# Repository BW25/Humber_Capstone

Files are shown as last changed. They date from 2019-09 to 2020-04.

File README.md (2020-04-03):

# Humber_Capstone
2019-2020 Computer Engineering Capstone Project at Humber College

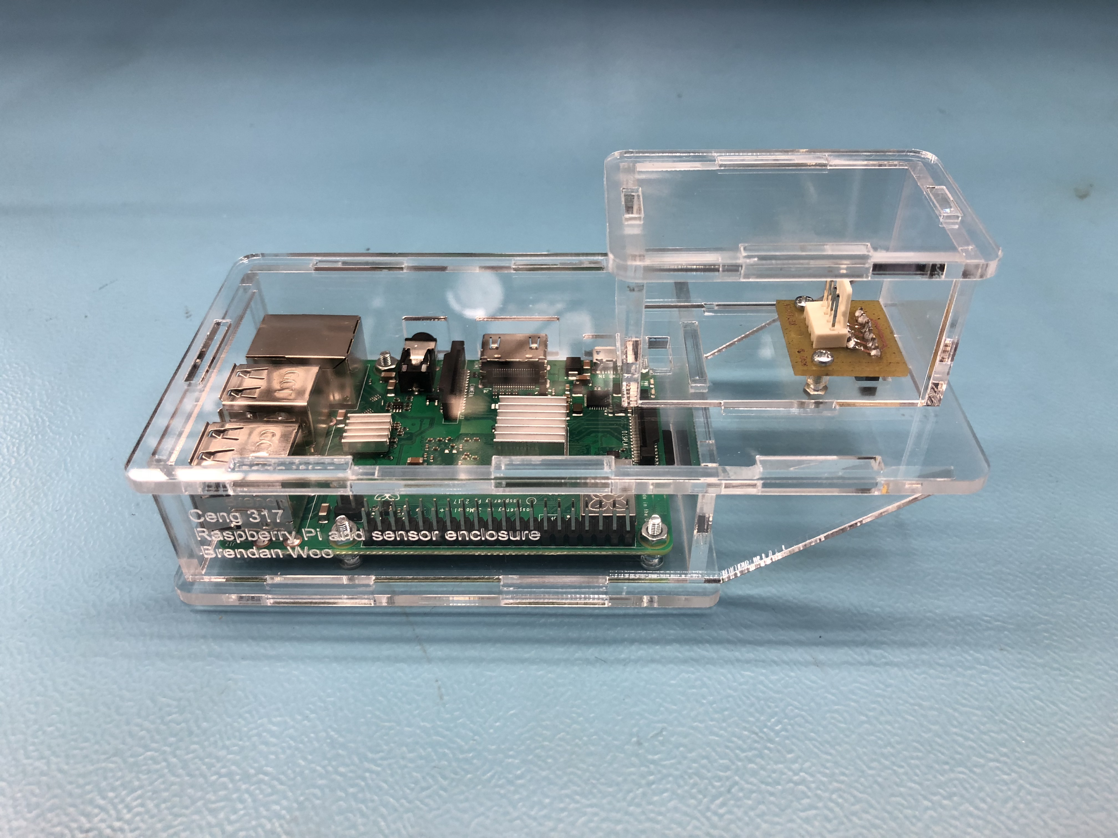
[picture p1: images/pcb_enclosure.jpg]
The final product


This guide will help you build a time-of-flight sensor, interface board, and laser-cut case for a Raspberry Pi development platform. The TOF sensor used is the VL53L0X sensor. This project was designed to serve as a piece of the hardware for a Resistor Value Recognizer device, but it can be used for other projects as well.

## Table of Contents
[Introduction](https://github.com/BW25/Resistor-value-recognizer#Introduction)

[Budget](https://github.com/BW25/Resistor-value-recognizer#Budget)

[Time committment](https://github.com/BW25/Resistor-value-recognizer#Time-committment)

[Software setup and Unit testing 1: Breadboard](https://github.com/BW25/Resistor-value-recognizer#Software-setup-and-Unit-testing-1-Breadboard)

[PCB / Soldering: Breadboard](https://github.com/BW25/Resistor-value-recognizer#PCB-/-Soldering)

[Unit testing 2: PCB](https://github.com/BW25/Resistor-value-recognizer#Unit-testing-2-PCB)

[Mechanical assembly](https://github.com/BW25/Resistor-value-recognizer#Mechanical-assembly)

[Power up and Unit testing 3: Production testing](https://github.com/BW25/Resistor-value-recognizer#Power-up-and-Unit-testing-3-Production-testing)

## Introduction

The Raspberry Pi development platform connects to the VL53L0X through an I2C bus. To make the connecttion and mounting of the sensor easier and more streamlined, an interface PCB was designed in Fritzing. The Raspberry Pi, sensor, and PCB are then enclosed in a laser-cut case for protection.

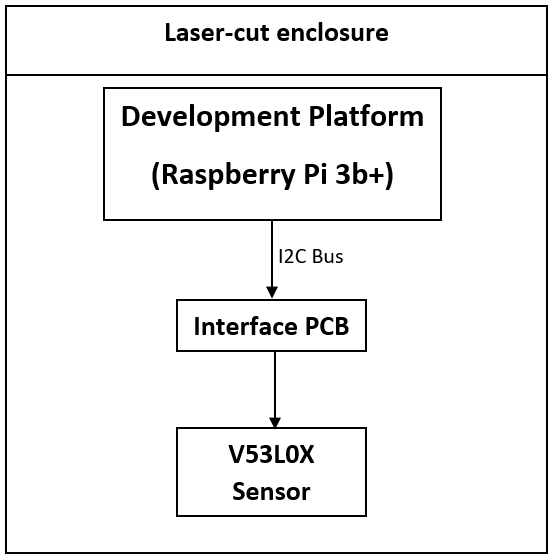
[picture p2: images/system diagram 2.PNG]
System Diagram 2

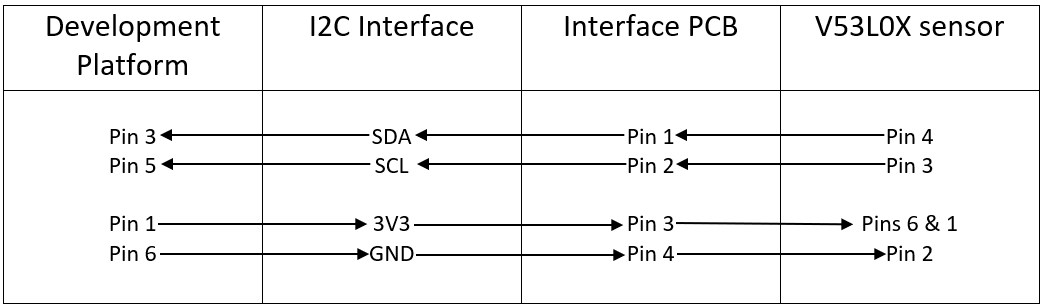
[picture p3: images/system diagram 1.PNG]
System Diagram 1


## Budget
[Full budget file](https://github.com/BW25/Resistor-value-recognizer/blob/master/documentation/Hardware%20(Ceng%20317)/Ceng317%20Budget%20BWoo%202019.xlsx)

The expected budget for the project is $144.52. However, the primary cost is a Raspberry Pi kit. If you already have one, then the cost will be $59.15. 

Here is a breakdown of all parts needed:

| Component | Number | Cost  |  Source  | Link |
|:---:|:---:|:---:|:---:|:---:|
| 3mm cast acrylic sheet | 1 |  $14.95 |  Amazon  | https://amzn.to/2Ry0JLj |
| m2.5 screws | 4 |  $0.60  |  Digikey | https://bit.ly/2t4eDuB |
| m2.5 nuts | 4 |  $0.92  |  Digikey | http://bit.ly/35lUwpC |
| m2 screws | 2 |  $0.42  |  Digikey | http://bit.ly/2PvBeYw |
| m2 nuts | 2 |  $0.34  |  Digikey | http://bit.ly/355GWqq |
| 4 pin header and 6 pin header | 1 |  $19.98 |  Amazon  | https://amzn.to/2PyRhVc |
| VL53L0X sensor | 1 |  $14.95 | Adafruit | https://www.adafruit.com/product/3317 |
| 4 F-F wire connectors | 1 |  $6.99  |  Amazon  | https://amzn.to/2RHou3L |
| Raspberry Pi kit | 1 |  $85.37 |  Canakit | https://amzn.to/2RHTccP |
| Total: | | $144.52 | | |

These components come with a Raspberry Pi Kit:

| Component | Number |
| --- | --- |
| Raspberry Pi | 1 |
| MicroSD card with Raspian | 1 |
| Raspberry Pi power supply | 1 |
| HDMI cable | 1 |

These components are expected to have no cost, as they are common enough that they are likely already possessed. The electronics are necessary to interface to the Raspberry Pi.

| Component | Number |
| --- | --- |
| Glue | 1 |
| Monitor with HDMI port | 1 |
| USB mouse | 1 |
| USB keyboard | 1 |

As shown below, the other main costs are the VL53L0X sensor and a sheet of 3mm cast acrylic for the enclosure. 

I have included resources to places where some of the resources can be purchased in the budget. Some components, such as the cast acrylic may have different availabilities depending on your location. Other components such as screws can be purchased at a local hardware store. 

I created my PCB in the Humber Prototype Lab, but you can order one from any PCB manufacturer, such as [Express PCB](https://www.expresspcb.com/how-to-order-pcbs/).
The PCB design can be edited in Fritzing, and can be found here: [PCB file](https://github.com/BW25/Resistor-value-recognizer/blob/master/electronics/TOFsensorDesign.fzz).

The AutoCAD files for the enclosure can be found here: [Hardware enclosure file](https://github.com/BW25/Resistor-value-recognizer/blob/master/mechanical/hardwareEnclosure.dwg)

## Time committment
As all design files are provided here, there is not a large expected time requirement for this project. As some components must be acquired from local retailers, additional time has been allotted to this part of the project. 
The total expected time is 3.5 hours. However, keep in mind it may take a few weeks for your parts and PCB to arrive after they have been ordered. 

| Task | Time |
| --- | --- |
| Parts order | 60 minutes |
| Breadboarding | 30 minutes |
| Soldering | 30 minutes |
| Laser cutting | 30 minutes |
| Mechanical assembly | 30 minutes |
| Power up | 15 minutes |
| Additional testing | 15 weeks |

## Software setup and Unit testing 1: Breadboard
It is recommended to test your sensor once it arrives to ensure it is functional.
This step also involves setting up the software. 

If your Raspberry Pi has not yet been set up with Raspian, you can find a step-by-step guide here.
[Raspberry Pi Tutorial](https://projects.raspberrypi.org/en/projects/raspberry-pi-setting-up)

Once your Raspberry Pi has been set up, you will need to enable the I2C bus. From the terminal, use the command "sudo raspi-config" to open the configuration window. 
Select "Interfacing Options". 
Highlight the “I2C” option and select it by pressing Enter. 
Select "Yes"
Close the configuration window

Now download the Raspberry Pi Python API.
It can be downloaded as a zip from this repository [here](https://github.com/BW25/Resistor-value-recognizer/blob/master/software/VL53L0X_rasp_python-master.zip).
Alternatively, you can download it from the [original source](https://github.com/johnbryanmoore/VL53L0X_rasp_python).

Set up your breadboard according to the wiring diagram provided. Now run the python code you downloaded. 
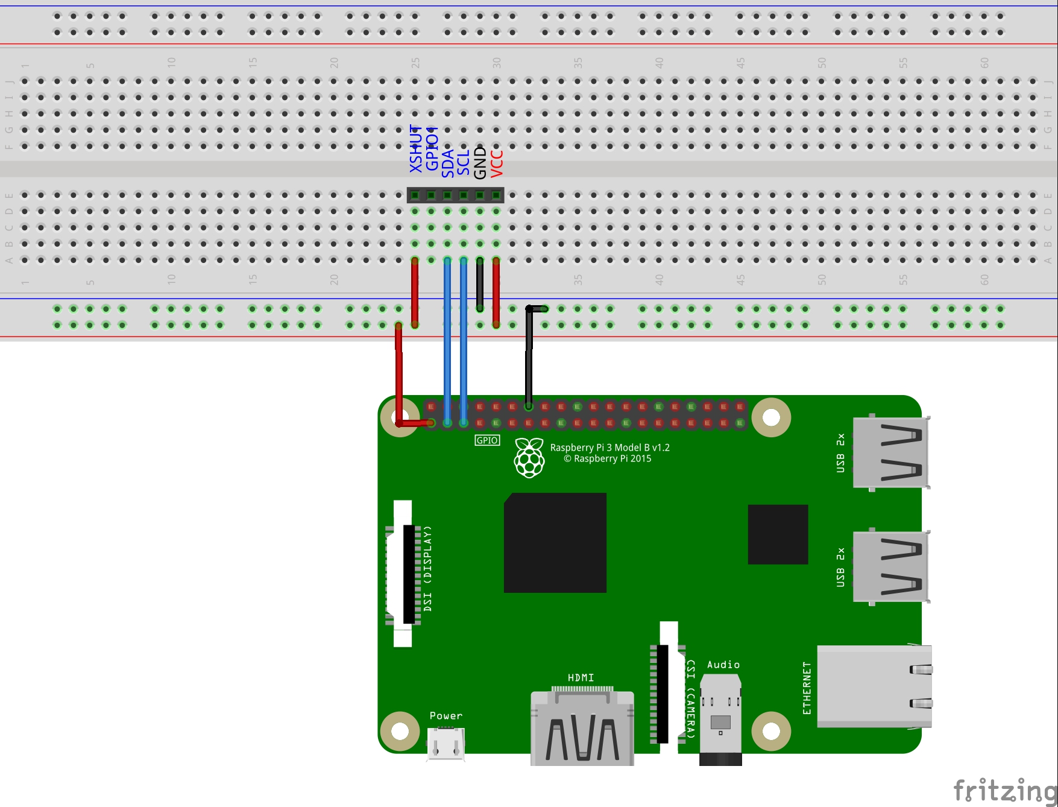
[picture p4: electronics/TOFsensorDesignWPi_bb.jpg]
Wiring diagram


Navigate to the code you downloaded and open the "python" folder. Run the python script "VL53L0X_example.py" in the command line.
If you are successful, you should see the code giving output similar to the image below. The value displayed should display the distance from the sensor to an object above it. 
Test it by moving your hand above the sensor while the code is running.

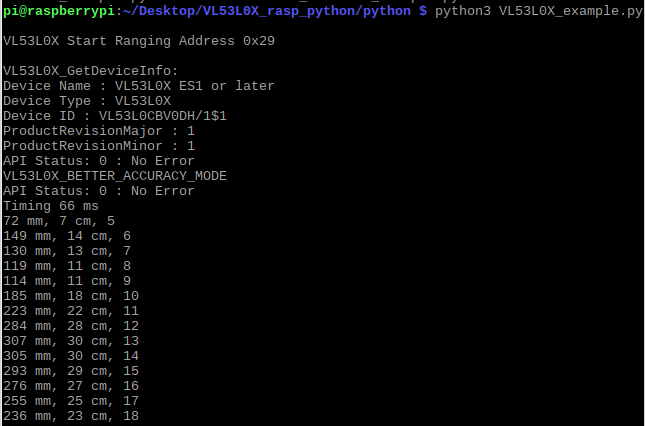
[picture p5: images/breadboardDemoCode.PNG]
Sample output


## PCB / Soldering

Once your PCB has arrived, it must be soldered. 
If you are unfamiliar with soldering, you can find a beginning tutorial here. [Soldering tutorials](https://www.youtube.com/watch?v=vIT4ra6Mo0s).

If you did not get a board with plated through holes, you will need to solder the center holes to ensure a connection between both sides of the boards. These holes are marked on the image below with black centers. Simply insert a short length of wire into the hole and solder on both ends.

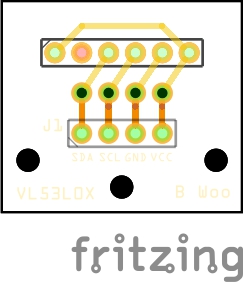
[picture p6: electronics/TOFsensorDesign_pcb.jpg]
PCB


The top side of the board is the side with the text. Do not solder the sensor directly onto the board. Instead, use a 6-pin header so the sensor can be inserted and removed without permanently attaching it to the board. Solder the 6-pin header to the bottom side of the board, and the 4 pin header to the top. The 4 pin header is where you will attach the wires between the board and the Raspberry Pi.

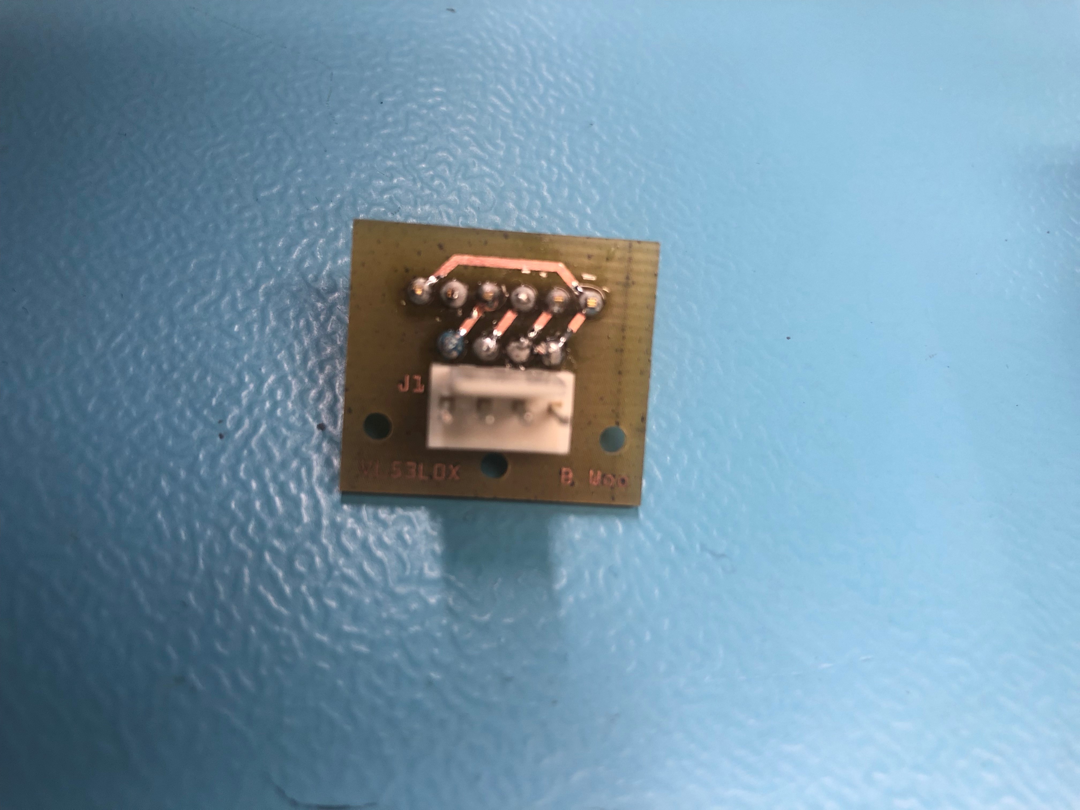
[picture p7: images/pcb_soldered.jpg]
Soldered PCB


## Unit testing 2: PCB
One your PCB is soldered, use a multimeter to ensure all of the pins are connected correctly. Refer to the labelling on the PCB itself and the schematic to ensure all pins are appropriately connected with no shorts. 
Then connect the PCB to the Raspberry Pi. You may use the same wiring on the Pi as in Unit testing 1, and the pins on the PCB are labelled, so this should be simple. Then run the code from Unit testing 1 to ensure the sensor and board are connected correctly. 
If it does not work, then recheck you interface board with a multimeter as above. If you cannot find a problem with the PCB, it may be necessary to recheck your sensor or Pi setup by repeating unit testing 1.

## Mechanical assembly

If you are unfamiliar with laser cutting, you can find a guide here. [Introduction to laser cutting](https://makerdesignlab.com/tutorials-tips/laser-cutting-beginners-guide/)

Laser cutting can be done in your local makerspace. A quick Internet search should let you find the one closest to you.

This project is designed for 3mm cast acrylic; colour is irrelevant, although I used transparent acrylic. You can cut other materials, but keep in mind the slots on the design are designed for a 3mm thick material. You may need to alter the design if you want to use something else. 
The AutoCAD files can be found at this link. I recommend altering it to change the text at minimum; you want it to say your name, not mine! [Hardware enclosure](https://github.com/BW25/Resistor-value-recognizer/blob/master/mechanical/hardwareEnclosure.dwg)

If you are unfamiliar with AutoCAD, you can find tutorials here. [AutoCAD tutorials](https://thesourcecad.com/autocad-tutorials/).

After editing the AutoCAD files, go to the "Output" tab and select "Plot". Change the plot scale to 1:1 in mm. Use the Preview button and the Plot offset to ensure your design is centered on the paper. Then select "Ok" to output your design to a PDF. 

If you do not wish to alter the enclosure, you may use this PDF output instead. [Hardware PDF](https://github.com/BW25/Resistor-value-recognizer/blob/master/mechanical/hardwareEnclosure-Model.pdf)

Bring your output PDF and and AutoCad files to the makerspace where you will laser cut your case. As the makerspace where you cut the acrylic could have a different model of laser cutter, please speak to the staff there for instructions on its use.

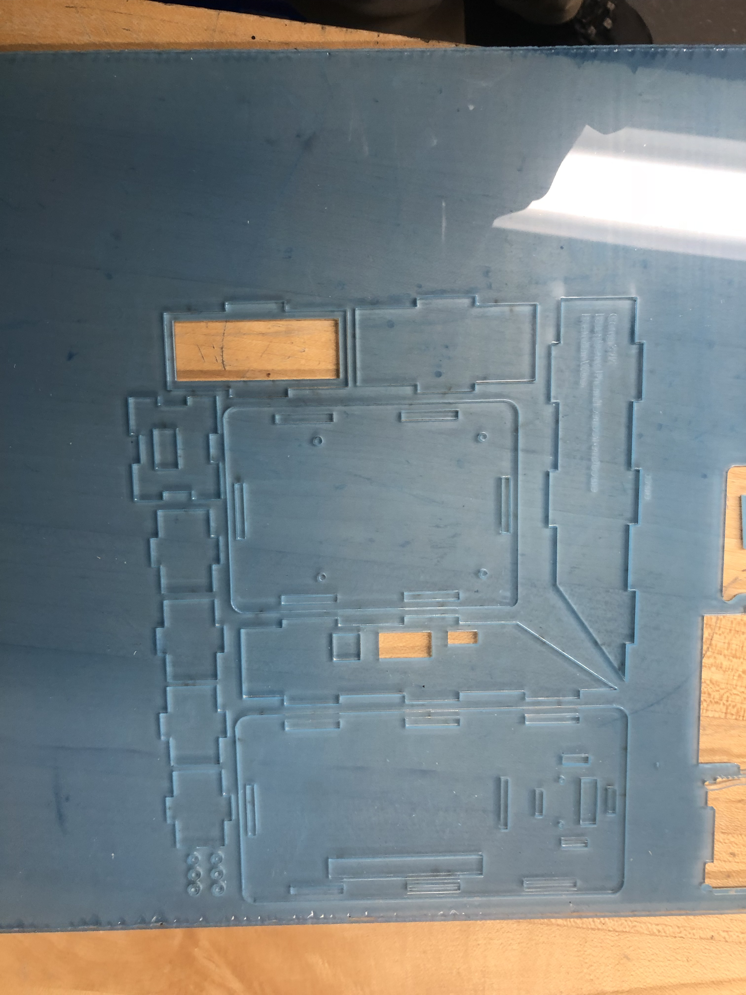
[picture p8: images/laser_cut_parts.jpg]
Laser cut pieces


The design is assembled shown in the image. Be sure that the side pieces with the holes are lined up with the ports on you Raspberry Pi. The small donut shaped pieces are standoffs for mounting your Raspberry Pi and PCB. Use the four larger standoffs and 4 m2.5 screws and nuts for the Raspberry Pi. The 2 smaller standoffs and 2 m2 screws and nuts are for your PCB. You may use acrylic glue to hold your case together. However, be sure not to glue the tops onto the case; friction will hold it in place, and gluing it shut means you can't remove your Raspberry Pi and PCB!

The final product

## Power up and Unit testing 3: Production testing

The final test is to interface our sensor to the Raspberry Pi in the case. Once the case is assembled, you will notice a small hole in the lid of the case. You can run the wires through here to connect the sensor and Raspberry Pi. Then connect the wiring and run the code as explained in Unit testing 1 and 2.

If you are assembling this project in larger numbers or are pressed for time, the multiple stages of unit testing may be undesirable or redundant. Therefore, this final check can be used for production testing.

If any clarification or assistance is required, please post in the Issues section.

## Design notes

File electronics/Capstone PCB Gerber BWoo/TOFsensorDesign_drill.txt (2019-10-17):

; NON-PLATED HOLES START AT T1
; THROUGH (PLATED) HOLES START AT T100
M48
INCH
T1C0.086614
T100C0.038000
T101C0.039370
%
T1
X008014Y001971
X004503Y000974
X001014Y001971
T100
X005014Y002971
X004014Y002971
X005014Y005971
X007014Y005971
X003014Y002971
X004014Y005971
X006014Y002971
X002014Y005971
X006014Y005971
X003014Y005971
T101
X004014Y004478
X005014Y004478
X006014Y004470
X003014Y004478
T00
M30

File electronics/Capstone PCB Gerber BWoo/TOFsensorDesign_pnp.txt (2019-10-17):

*Pick And Place List
*Company=
*Author=
*eMail=
*
*Project=TOFsensorDesign
*Date=14:49:19
*CreatedBy=Fritzing 0.9.3b.04.19.5c895d327c44a3114e5fcc9d8260daf0cbb52806
*
*
*Coordinates in mm, always center of component
*Origin 0/0=Lower left corner of PCB
*Rotation in degree (0-360, math. pos.)
*
*No;Value;Package;X;Y;Rotation;Side;Name
1;;;5.17913;-1.68191;0;Top;TXT1
2;;;12.751;-5.15002;0;Top;TXT1
3;;;19.1006;-1.83685;0;Top;TXT1
4;;;10.1972;-11.3746;0;Bottom;Via3
5;;;10.3267;-5.16554;0;Top;TXT1
6;;;2.57712;-5.00764;0;Bottom;Hole3
7;;;4.8855;-8.12504;0;Top;TXT1
8;;;11.4392;-2.47526;0;Bottom;Hole4
9;;;7.65722;-11.3746;0;Bottom;Via4
10;;THT;11.4672;-7.54754;-90;Bottom;J3
11;;;7.72183;-5.16865;0;Top;TXT1
12;;;12.7372;-11.3746;0;Bottom;Via2
13;;;15.1925;-5.1709;0;Top;TXT1
14;;;15.2772;-11.3563;0;Bottom;Via1
15;;;20.3571;-5.00764;0;Bottom;Hole1
16;;THT;11.4672;-15.1675;-90;Bottom;J2

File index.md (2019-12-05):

## Blog
### Resistor Value Recognizer
#### Brendan Woo, Husnal Kaur

## Repository
[https://github.com/BW25/Resistor-value-recognizer](https://github.com/BW25/Resistor-value-recognizer "Repository")

### November 28, 2019 (Week 11)

The presentation has been completed, and the project is proceeding on schedule.

As previously stated, the budget is also on track

[Presentation](https://github.com/BW25/Resistor-value-recognizer/blob/master/documentation/Hardware%20(Ceng%20317)/Project%20Presentation.pptx)

### November 21, 2019 (Week 10)
The PCB enclosure has been created, and now all hardware and software has been completed.

With no more expenses left to make, the final budget is as detailed in the budget.

The project is also on schedule, and work is beginning on the project presentation and build instructions.

PCB enclosure

### November 14, 2019 (Week 9)
The PCB has been tested with the development platform.

With the PCB confirmed to be functional, work is now beginning on the hardware enclosure, as per the project schedule.

The proposal is being adhered to, and the project is on budget.

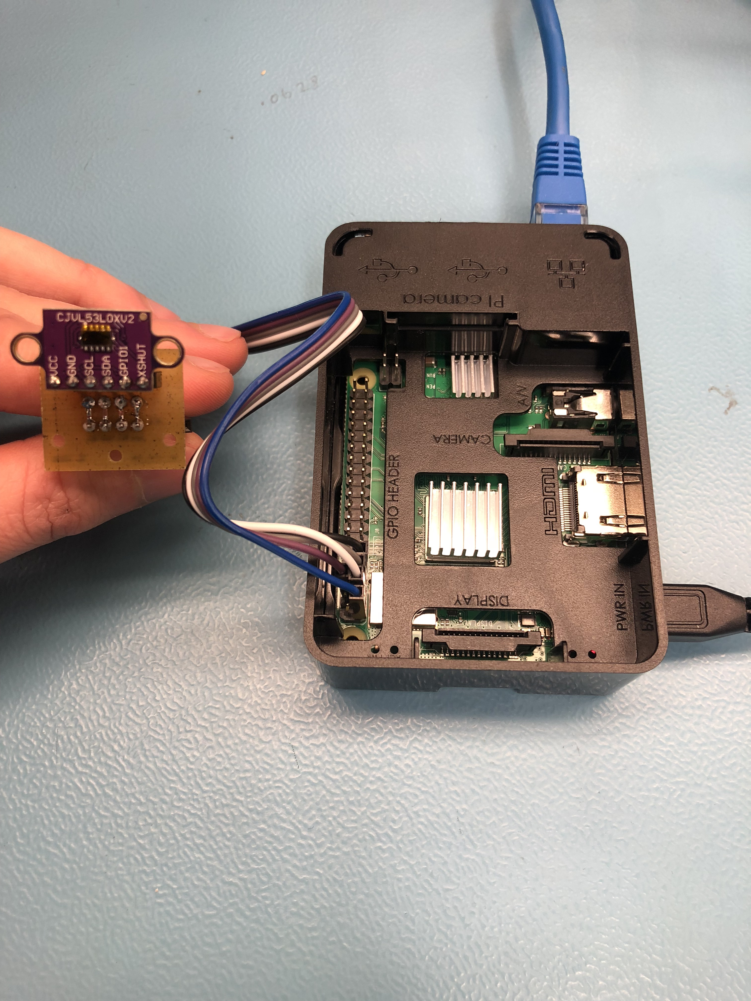
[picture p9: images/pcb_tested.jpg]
PCB tested


### November 7, 2019 (Week 9)
The PCB has been soldered and tested.

The project is on schedule and on budget.

PCB

### October 31, 2019 (Week 8)
The breadboard demo is now complete, and the sensor tested. Happy Halloween!

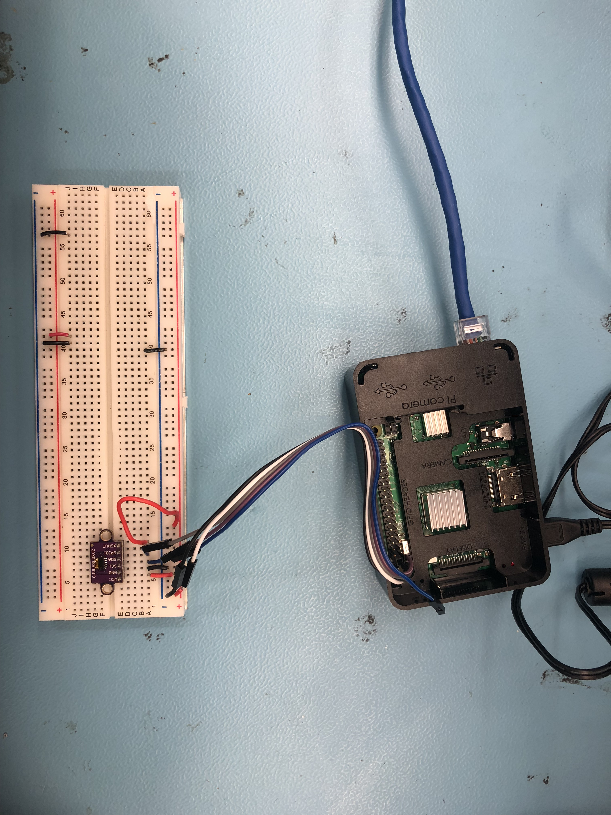
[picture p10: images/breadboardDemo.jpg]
Breadboard


Breadboard Code

### October 10, 2019 (Week 6)
The breadboard, schematic, and PCB designs are now complete.

All components needed for the breadboard have also been purchased.

The project is on track in terms of both the schedule and the budget, and the proposal is being followed.

Breadboard

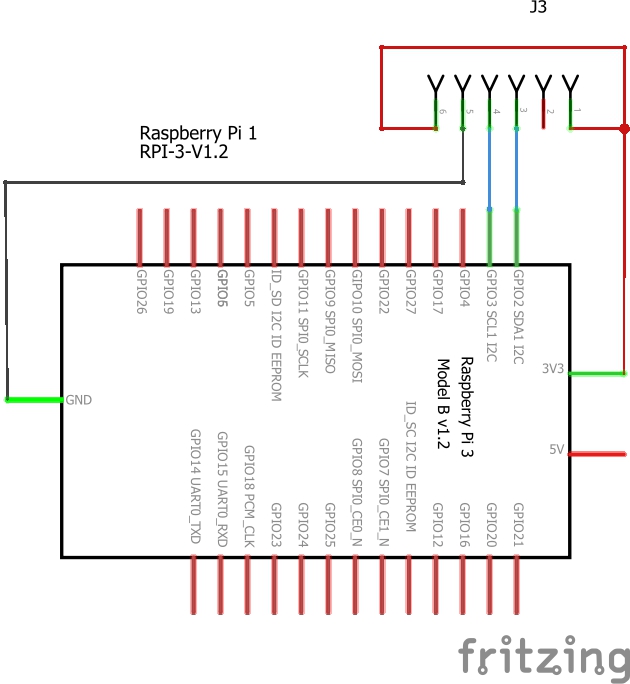
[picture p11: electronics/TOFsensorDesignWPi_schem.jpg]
Schematic


PCB

### October 03, 2019 (Week 5)
Parts have been ordered, and some have already arrived

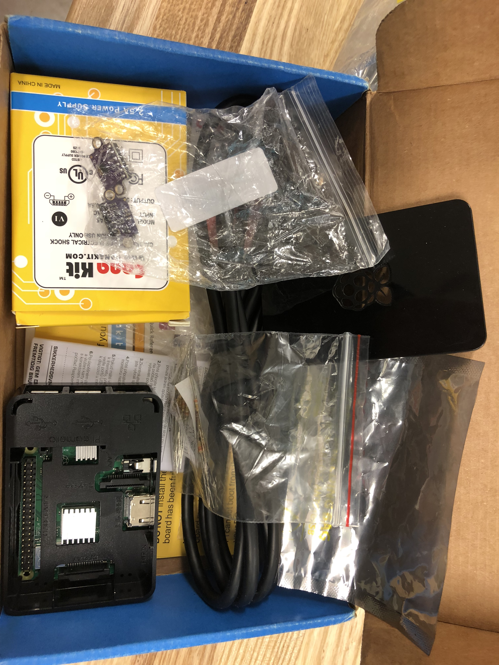
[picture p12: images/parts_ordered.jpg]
Parts Ordered Image Parts Ordered


### September 26, 2019 (Week 4)
[App layout mockup created](https://github.com/BW25/Resistor-value-recognizer/blob/master/documentation/Software%20(Ceng%20319)/Ceng%20319%20App%20mockup%20BWoo%20HKaur.pdf "App Mockup")

[App schedule created](https://github.com/BW25/Resistor-value-recognizer/blob/master/documentation/Software%20(Ceng%20319)/Ceng319%20Project%20Schedule%20Husnal%20Brendan.pdf "App schedule")

### September 19, 2019 (Week 3)
Working on colour recognition to read the resistor colour code.

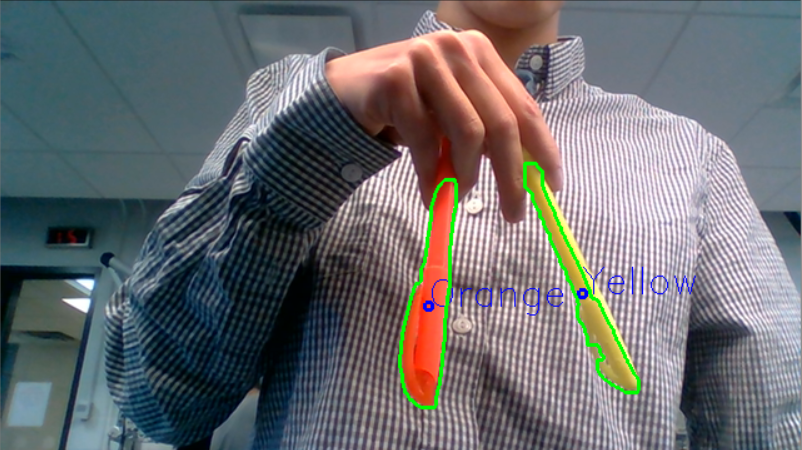
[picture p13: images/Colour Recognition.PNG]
Colour Recognition Image Colour Recognition


[Project budget written](https://github.com/BW25/Resistor-value-recognizer/blob/master/documentation/Hardware%20(Ceng%20317)/Ceng317%20Budget%20BWoo%202019.xlsx "Budget")

### September 12, 2019 (Week 2)
[Project schedule written](https://github.com/BW25/Resistor-value-recognizer/blob/master/documentation/Hardware%20(Ceng%20317)/Ceng317%20Project%20Schedule%20BWoo.png "Schedule")

### September 5, 2019 (Week 1)
This project will be a resistor value recognizer to help employees at Humber's Parts Crib as well as new students to quickly identify and organize resistors. It will include a base station that connects to an Android app.

[Project proposal written](https://github.com/BW25/Resistor-value-recognizer/blob/master/documentation/Hardware%20(Ceng%20317)/Ceng317_Proposal_ResistorValueRecognizer_Kaur-Woo.pdf "Proposal")

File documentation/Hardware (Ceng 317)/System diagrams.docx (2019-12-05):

Development Platform | I2C Interface | Interface PCB | V53L0X sensor
Pin 3 Pin 5 Pin 1 Pin 6 | SDA SCL 3V3 GND | Pin 1 Pin 2 Pin 3 Pin 4 | Pin 4 Pin 3 Pins 6 & 1 Pin 2

Laser-cut enclosure

V53L0X Sensor

I2C Bus

Interface PCB

Development Platform

(Raspberry Pi 3b+)

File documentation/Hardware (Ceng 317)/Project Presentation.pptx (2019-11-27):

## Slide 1

TOF sensor for Resistor Value Recognizer

Ceng 317
Brendan Woo

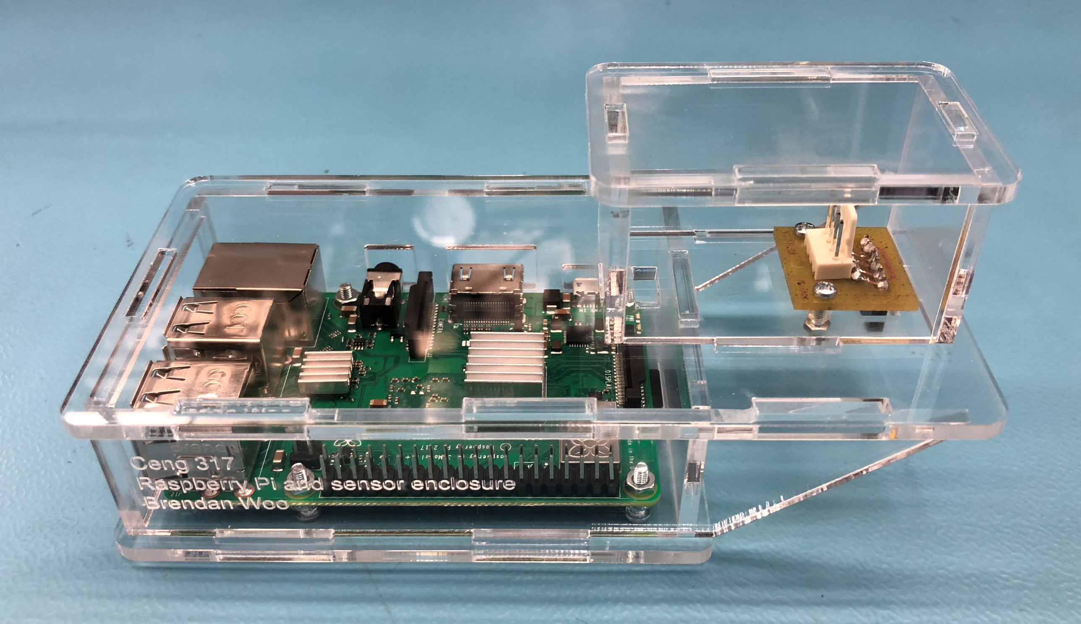
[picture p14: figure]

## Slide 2

Proposal

- The Capstone is a Resistor Value Recognizer to reduce traffic at the Parts Crib
- The camera and lighting system must be
triggered by the insertion of a resistor
- A Time of Flight infrared sensor will be used to
detect the movement for this purpose

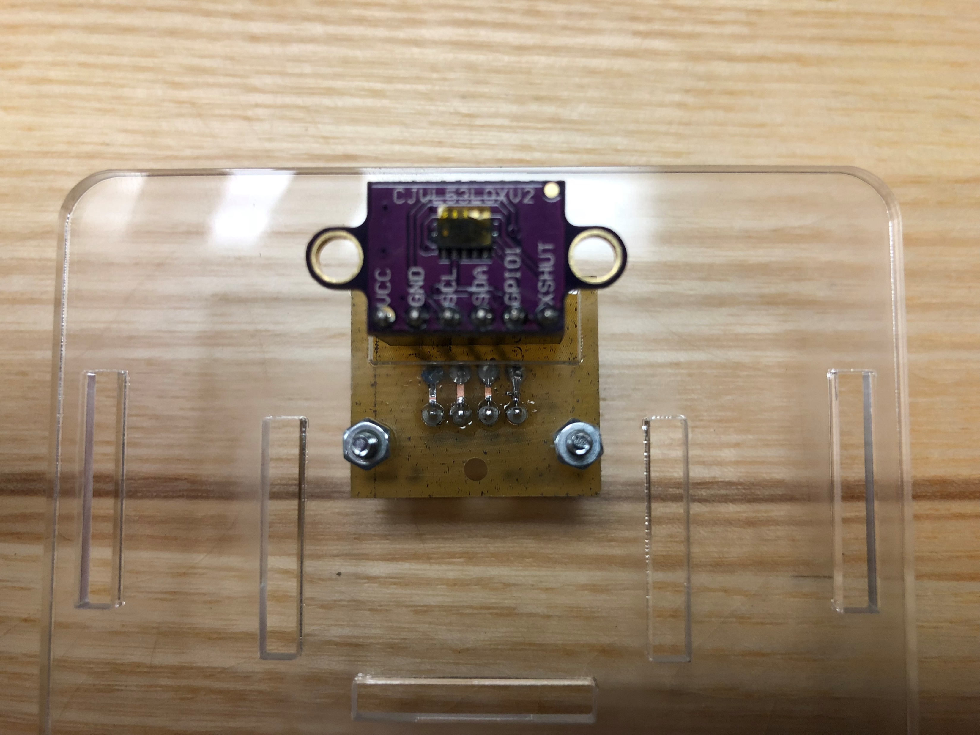
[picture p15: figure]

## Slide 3

Expenses

- Original projected budget was $124.19
- Many components were already acquired or supplied by the Prototype lab:
As a result, final expenses were $105.89
- Total expenses during the course of the project were $5.57

Purchase | Cost | Number | Total cost | Notes | Status | Source
VL53L0X TOF sensor | $14.95 | 1 | $ 14.95 | | Previously purchased | https://www.adafruit.com/product/3317
23x11 3mm transparent cast acrylic | $11.30 | 1 | $ 11.30 | For case | No cost | Supplied by prototype lab
Standoffs M-M (x4) | $2.50 | 1 | $ 2.50 | For case | No cost | Supplied by prototype lab
Standoffs M-F (x2) | $1.50 | 2 | $ 3.00 | For case | No cost | Supplied by prototype lab
Screws | $1.50 | 1 | $ 1.50 | For case | No cost | Supplied by prototype lab
Wires | $0.00 | 0 | $ - | | Previously purchased
Header pin and connectors | $ 5.57 | 1 | $ 5.57 | | | Sayal
Raspberry Pi kit | $ 85.37 | 1 | $ 85.37 | Current price is lower | Previously purchased | https://www.amazon.com/CanaKit-Raspberry-Complete-Starter-Kit/dp/B01C6Q2GSY
Expected budget | $124.19
Total | $105.89
Total project-specific | $5.57

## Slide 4

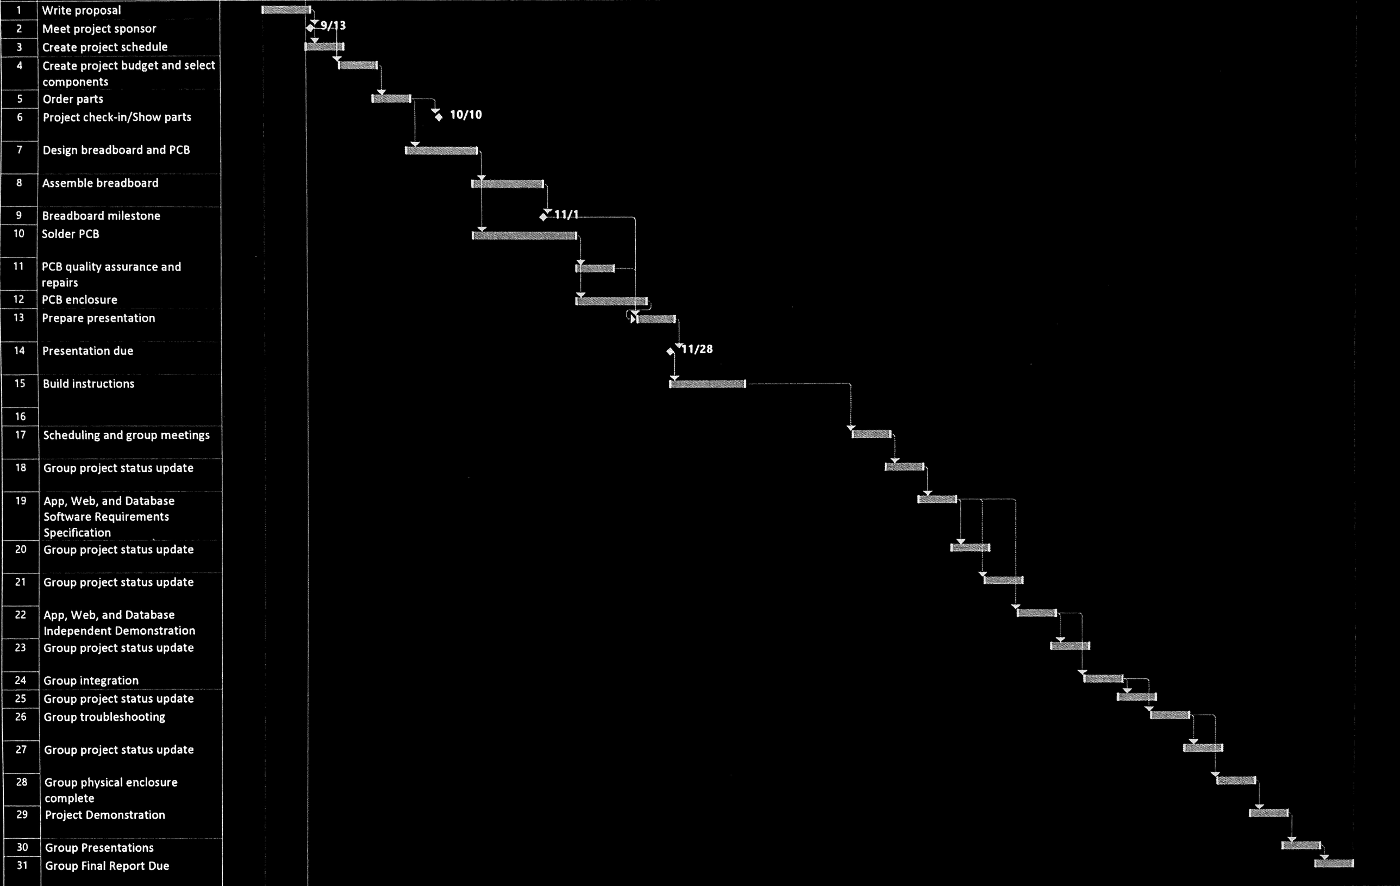
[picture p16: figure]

Schedule

- Proposal
- Schedule
- Budget
- Breadboard milestone
- PCB milestone
- Enclosure milestone
- Presentation
- Build instructions

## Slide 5

Final Product

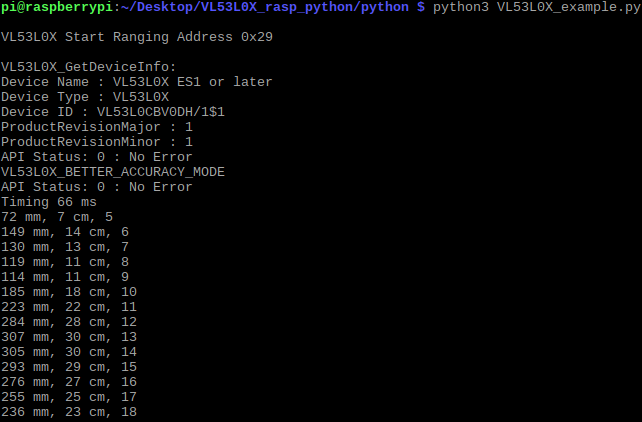
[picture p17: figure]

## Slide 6

Applied Knowledge

- Tech 150: Electronic Devices and Circuits
  - Soldering, breadboarding, circuit troubleshooting
- Ceng 252: Embedded Systems
  - Prototyping and programming on Raspberry Pi development platform
- Ceng 215: Digital and Interface Systems
  - Sensor control and interfacing

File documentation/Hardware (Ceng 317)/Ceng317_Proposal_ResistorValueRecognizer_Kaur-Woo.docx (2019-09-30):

43718

Proposal for the development of Resistor value recognizer

Prepared by Brendan Woo, Husnal Kaur
Computer Engineering Technology Students
https://github.com/BW25/Resistor-value-recognizer

Executive Summary

As a student in the Computer Engineering Technology program, I will be integrating the knowledge and skills I have learned from our program into this Internet of Things themed capstone project. This proposal requests the approval to build the hardware portion that will connect to a database as well as to a mobile device application. The internet connected hardware will include a custom PCB with the following sensors and actuators Time-of-flight sensor , luminosity sensor, camera. The database will store User account information, History of recognized resistors, Resistor color code lookup table,. The mobile device functionality will include Viewing value of resistor, Viewing history, Color code table with values and will be further detailed in the mobile application proposal. I will be collaborating with the following company/department Humber parts crib. In the winter semester I plan to form a group with the following students, who are also building similar hardware this term and working on the mobile application with me Brendan Woo, Husnal Kaur. The hardware will be completed in CENG 317 Hardware Production Techniques independently and the application will be completed in CENG 319 Software Project. These will be integrated together in the subsequent term in CENG 355 Computer Systems Project as a member of a 2 or 3 student group.

Background

The problem solved by this project is Due to the large volume of students that use the parts crib, large amounts of unsorted components often accumulate. High traffic makes it difficult to sort these components, and it is often time consuming to figure out each and every value of the resistors. Also, it can be hard to identify resistor values correctly in a fast paced environment.. A bit of background about this topic is When a component is inserted into a processing area, image processing and machine learning will be used to recognize resistor values through object and colour recognition. Once the resistor's value has been found, this can be logged in a database to track usage. This information can be accessed by an Android app so the user’s ID can be used to look up their history. A time-of-flight sensor will be used to detect when an object is inserted. As image processing techniques are dependent on lighting, a luminosity sensor will be used to trigger a lighting system to ensure ideal lighting conditions are always present. The time-of-flight sensor will then trigger both the camera and the lighting system for greater energy efficiency..

Existing products on the market include [1]. I have searched for prior art via Humber’s IEEE subscription selecting “My Subscribed Content”[2] and have found and read [3] which provides insight into similar efforts.

In the Computer Engineering Technology program we have learned about the following topics from the respective relevant courses:

- Java Docs from CENG 212 Programming Techniques In Java,
- Construction of circuits from CENG 215 Digital And Interfacing Systems,
- Rapid application development and Gantt charts from CENG 216 Intro to Software Engineering,
- Micro computing from CENG 252 Embedded Systems,
- SQL from CENG 254 Database With Java,
- Web access of databases from CENG 256 Internet Scripting; and,
- Wireless protocols such as 802.11 from TECH152 Telecom Networks.

This knowledge and skill set will enable me to build the subsystems and integrate them together as my capstone project.

Methodology

This proposal is assigned in the first week of class and is due at the beginning of class in the second week of the fall semester. My coursework will focus on the first two of the 3 phases of this project:
Phase 1 Hardware build.
Phase 2 System integration.
Phase 3 Demonstration to future employers.

Phase 1 Hardware build

The hardware build will be completed in the fall term. It will fit within the CENG Project maximum dimensions of 12 13/16" x 6" x 2 7/8" (32.5cm x 15.25cm x 7.25cm) which represents the space below the tray in the parts kit. The highest AC voltage that will be used is 16Vrms from a wall adaptor from which +/- 15V or as high as 45 VDC can be obtained. Maximum power consumption will be 20 Watts.

Phase 2 System integration

The system integration will be completed in the fall term.

Phase 3 Demonstration to future employers

This project will showcase the knowledge and skills that I have learned to potential employers.

The brief description below provides rough effort and non-labour estimates respectively for each phase. A Gantt chart will be added by week 3 to provide more project schedule details and a more complete budget will be added by week 4. It is important to start tasks as soon as possible to be able to meet deadlines.

cast acrylic for component casings, time-of-flight sensor, luminosity sensor, Raspberry Pi camera module, assorted screws, standoffs, and bolts

Concluding remarks

This proposal presents a plan for providing an IoT solution for This system will make it easier for both students and professionals to recognize resistor values in a fast and efficient manner.. This is an opportunity to integrate the knowledge and skills developed in our program to create a collaborative IoT capstone project demonstrating my ability to learn how to support projects such as the initiative described by [3]. I request approval of this project.

References

[1] Amazon. (2019, September 05). Amazon Go. Retrieved from Amazon.com: https://www.amazon.com/b?node=16008589011

[2] Institute of Electrical and Electronics Engineers. (2015, August 28). IEEE Xplore Digital Library [Online]. Available: https://ieeexplore.ieee.org/search/advsearch.jsp

[3] Cruz, J., Dimaala, M., Francisco, L., Franco, E., & Bandala, A. (2013). Object recognition and detection by shape and color pattern recognition utilizing Artificial Neural Networks. 2013 International Conference of Information and Communication Technology (ICoICT).

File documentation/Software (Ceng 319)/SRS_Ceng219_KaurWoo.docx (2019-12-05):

# Software Requirements Specification

# for

# Resistor Value Recognizer

Version 1.0 approved

Prepared by Husnal Kaur, Brendan Woo

Humber College Computer Engineering Technology

2019-10-02

Table of Contents

1. Introduction 1

1.1 Purpose 1

1.2 Product Scope 1

1.3 Intended Audience and Reading Suggestions 1

1.4 References 1

2. Overall Description 1

2.1 Product Perspective 1

2.2 Product Functions 2

2.3 User Classes and Characteristics 2

2.4 Operating Environment 2

2.5 Design and Implementation Constraints 2

2.6 User Documentation 2

2.7 Assumptions and Dependencies 2

3. External Interface Requirements 3

3.1 User Interfaces 3

3.2 Hardware Interfaces 3

3.3 Communications Interfaces 3

4. System Features 3

4.1 System Feature 1 3

4.2 System Feature 2 (and so on) 4

5. Other Nonfunctional Requirements 4

5.1 Performance Requirements 4

5.2 Safety Requirements 4

5.3 Security Requirements 4

5.4 Software Quality Attributes 4

5.5 Business Rules 5

6. Other Requirements 5

Revision History

Name | Date | Reason For Changes | Version
Woo, Kaur | 2019-10-02 | Initial report | 1.0

# 1. Introduction

## 1.1 Purpose

The project is a Resistor Value Recognizer (RVR) app. Its main functionality is to connect to a device which scans and displays the colour coded value of a resistor. Due to the large volume of students that use the parts crib, significant amounts of unsorted components often accumulate from returned components. High traffic makes it difficult to sort these components quickly, and it is often time consuming to figure out each and every value of the resistors. Moreover, it can be hard to identify resistor values correctly in a fast-paced environment. Current revision number is 1.0.

## 1.2 Product Scope

The app communicates with a database which records usage of the Resistor Value Recognizer hardware platform for each user. It also provides an interface with which to communicate with the companion device and a GUI to view resistor values. Both live scans and the history of previous scans can be viewed via the app, making for easy organizing of resistors. The goal is to provide a user-friendly means of controlling the device and accessing their data hosted on the server.

## 1.3 Intended Audience and Reading Suggestions

This document is targeted towards the following types of audience:

- Humber College Parts Crib Employees
- Students from various Schools, Colleges and Universities
- Professionals working in a fast paced environment
- Developers looking to develop applications interfacing with the server

For the best understanding of this document, the readers are suggested to become familiar with concepts like server, database, GUI(Graphical User Interface) and information communication.

## 1.4 References

These sources were used in the ideation of this project, and can be used for reference.

- Amazon. (2019, September 05). Amazon Go. Retrieved from Amazon.com: https://www.amazon.com/b?node=16008589011
- Cruz, J., Dimaala, M., Francisco, L., Franco, E., & Bandala, A. (2013). Object recognition and detection by shape and color pattern recognition utilizing Artificial Neural Networks. 2013 International Conference of Information and Communication Technology (ICoICT).

# 2. Overall Description

## 2.1 Product Perspective

This project is a Capstone Project for Humber College’s Computer Engineering Technology program. As a result, this is a standalone project consisting of both the hardware and software of a companion device, a web server, and the Android app. The app and companion device will communicate via the web server, which stores relevant user data as well as data used to control the companion device from the app.

Data flow:

Companion Device

Web server

Android App

## 2.2 Product Functions

The app provides the following core functionalities, explained further in Section 3

- Communications with the database
- History viewing
- Resistor Color Code Lookup table
- User account management

## 2.3 User Classes and Characteristics

This application and the companion device are mainly targeted towards three different types of users:

1. Humber College Parts Crib: The parts crib has, at any given time, high amount of various components which are to be sorted in different spaces. This device and app will help them quickly identify resistor values without going through the process of calculating them manually.
2. Students (Schools/Colleges/University): Students who are unfamiliar with resistor color codes and how to calculate the values of resistors can easily use the app and the device to find the value without having to look up online.
3. Professionals working in a fast paced environment: This app will bring ease of resistor identification to professionals who use multitude of resistors on a daily basis. It will be easier and faster for them to get the values and store them in the history of the application than either calculating the value every time or putting the resistor inside the physical device again.

## 2.4 Operating Environment

The software will operate as an app on an Android phone running Android 7 (Nougat), API 24. The targeted minimum API of the app is 19 (Kitkat) to ensure compatibility. It must run alongside other applications which may be making use of the same hardware resources, including the camera and Wi-Fi.

## 2.5 Design and Implementation Constraints

- The app and its features can only be accessed by using an account created on the app. Without creating an account, the user can’t use the history feature or view the initial scanning/QR screen to connect to the device via the app.
- The physical device and the app can only work in the vicinity of Wi-Fi connection, since all the data flow and calculation happens on the server and a network connection is necessary for communication.
- The app will only work in conjugation to the hardware device, without the device the app has no recognition power of its own. A resistor colour code lookup table will be included in the app to provide some functionality to the user without the additional hardware.

## 2.6 User Documentation

All documentation is available on the following Github repositories:

- https://github.com/BW25/Resistor-value-recognizer
- https://github.com/HusnalK/Resistor-Value-Recoganizer-RVR

## 2.7 Assumptions and Dependencies

The operating environment must have access to power and Wi-Fi for the companion device, and a Wi-Fi or cellular data connection for the phone to communicate with the database. The database will be a Google Firebase server, which must be online for the app to connect to it.

# 3. External Interface Requirements

## 3.1 User Interfaces

The app’s user interface is the GUI displayed on the Android device. A menu bar will be provided at the bottom of the screen for navigation through app activities. The activities accessed via the menu bar include:

- Scan activity: viewing live scans from the device
- History activity: viewing past scans
- Lookup activity: access a resistor code lookup table
- Settings activity: Change app settings, user account info, or connect to a companion device

The app opens with user login and device connection (if necessary) and then the user is sent to the Scan screen, from which they can navigate to other activities via the menu bar.

The app GUI mockup can be found with the following link:

https://github.com/BW25/Resistor-value-recognizer/blob/master/documentation/Software%20(Ceng%20319)/Ceng%20319%20App%20mockup%20BWoo%20HKaur.pdf

## 3.2 Hardware Interfaces

The app is designed for Android devices with a GUI created for Android phone screens. The minimum API targeted is intended to be API 19, Kitkat, to ensure compatibility with 95% of Android devices, as of the date of this document’s creation. The phone’s Wi-Fi capabilities will be used to connect to a Google Firebase server to access data from the hardware. The phone’s camera will also be used to scan QR codes that will be used to identify to the app which device they should connect to.

## 3.3 Communications Interfaces

The web server will serve as the communications interface between the app and the companion device. User data will be communicated for user login and account management. Details of resistor scans, including resistor values and scan timestamps are expected to be the most common data received by the app. The app will also send data for the purpose of controlling the device, specifically, logging the user’s usage of the device and triggering the companion device to scan.

# 4. System Features

## 4.1 Communications with the database

4.1.1 Description and Priority

The app must be capable of connecting and communicating with the web server for sharing data with the companion device, which also sends data to the web server.

This requirement is the highest priority (9), as it is a prerequisite for requirements 2 (User account management) and 3 (History viewing).

4.1.2 Stimulus/Response Sequences

Inputs will come from the user, who will scan a QR code on the device. The QR code stores the name of the device, which identifies it on the database, allowing the app to communicate with it. The necessary data to connect to the database will be stored internally by the app. Outputs will appear on the GUI, indicating the status of the device.

4.1.3 Functional Requirements

REQ-1: App connects with database

The app must initiate communication with the web server and connect to access the data in the database. The app’s control of the database must be set so the app may only edit the user’s own information under certain conditions, and only manage their own history.

REQ-2: App updates device command table to control the device

The app must trigger the device to take a picture of a resistor and extract the colour code, then log it to the database

## 4.2 User account management

4.1.1 Description and Priority

The user must be able to create a new account or log into an existing one. They must also be able to modify their account via the Settings activity. This requirement is the second highest priority (8) as it has the prerequisite of Requirement 1 (Communications with database), and is a prerequisite for Requirement 3 (History viewing).

4.1.2 Stimulus/Response Sequences

The user will input their username and password from the login/signup activity, which will be used to control the user’s access to the database. Only when the user is logged in will they be able to progress to the other activities.

4.1.3 Functional Requirements

REQ-1: Sign up

A new user must be able to create a new account to access the database and store their data within it.

REQ-2: Log in

A user with a pre-existing account must be able to log in to access their data.

REQ-3: Update user information

A user should be able to modify their account information, including changing their email, password, and deleting their account

## 4.3 History viewing

4.1.1 Description and Priority

The app must be capable of viewing data of resistor scans corresponding to the logged in user and displaying it in a GUI for the user. This has the third highest priority (7), as it is one of the core functionalities of the app, but has the prerequisite of Feature 1 (Communications with companion device), and Feature 2 (User account management).

4.1.2 Stimulus/Response Sequences

Inputs will include the user’s id, obtained when the user logs in. This allows the app to use the database connection to access the resistor scans belonging to that user.

4.1.3 Functional Requirements

REQ-1: Access user’s history

The database connection will be used to read from the table storing the history of the logged in user

REQ-2: Display history to GUI

The history will be displayed to the History activity, with the most recent scan appearing in both Scan activity and History activity.

REQ-3: Delete user’s history

Users should have the option of deleting their history to give the user control over their data and free space in the database

## 4.4 Resistor colour code lookup table

4.1.1 Description and Priority

The user must be able to access a resistor code lookup table used as a learning tool, or in the event a connection to the database is not possible. This requirement has a lower priority (5), as it is not required for the core functionality of the app and serves as a backup in the event other features are not available due to lack of wireless connection.

4.1.2 Stimulus/Response Sequences

The only input required is the user selecting the Colour Code activity, which displays the colour code lookup table to the GUI

4.1.3 Functional Requirements

REQ-1: Colour code lookup activity

The colour code activity must be created and accessible through the menu bar

REQ-2: Lookup table

The lookup table must be created and stored in the app’s resources so it can be displayed to the GUI

# 5. Other Nonfunctional Requirements

## 5.1 Performance Requirements

The project heavily depends on the database connection to and from the device and the app. High speed wifi and/or mobile data connections are needed for optimum performance. The information sent to the database for establishing the connection between the app and the device via the QR code scanner should also be accurate for the functioning of the system. The system must be capable of recognizing resistors quickly to have utility and increased usability compared to the user figuring out the resistor codes themselves.

## 5.2 Safety Requirements

The app must not make unnecessary use of the phone’s resources and take care not to have data leaks that could affect other functionalities of the phone. Upon uninstalling the app, all relevant data should be removed.

## 5.3 Security Requirements

The user’s login/signup information should be saved in a secure way on the database with all the required security protections applied, especially in the case of storing the password. The password should be appropriately hashed and salted. The user also should not have any direct access to the database.

## 5.4 Software Quality Attributes

The primary quality characteristics for the end user are availability, accuracy, reliability, and speed. The end user expects the app to work in a quick, efficient, and easy to use manner.

The primary quality characteristics for the developers are maintainability, accuracy, robustness, interoperability, testability, efficiency, and portability.

The developers need the app to be easy to maintain and capable of functioning well with other components of the system in a testable and verifiable manner.

# 6. Other Requirements

The app must conform with the project guidelines of Ceng 319 at Humber College, and include the required activities, features, and functionality detailed in the course documentation.

Software Requirements Specification for Resistor Value Recognizer Page 2

Software Requirements Specification for Resistor Value Recognizer Page 4

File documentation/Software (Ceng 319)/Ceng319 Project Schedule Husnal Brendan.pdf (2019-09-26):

ID | Task
Mode
| Task Name | Duration | Start | Finish | Predecessors
1 | Project proposal | 6 days | Wed 9/11/19Wed 9/18/19
2 | Partner meeting | 0 days | Thu 9/19/19 | Thu 9/19/19 | 1
3 | Make project schedule | 5 days | Wed 9/25/19 | Tue 10/1/19 | 2
4 | Make app mockup | 5 days | Wed 9/25/19Tue 10/1/19 | 1
5 | Requirements analysis | 1 day | Wed 10/2/19 | Wed 10/2/19 | 4,3
6 | Implementing first 4 app activities | 5 days | Thu 10/3/19 | Wed 10/9/19 | 5
7 | Partner meeting | 0 days | Thu 10/10/19Thu 10/10/194,5
8 | Implementing final 4 app activities | 3 days | Thu 10/10/19 | Mon 10/14/19 | 6
9 | Prepare presentation 1 day? | Tue
| | | 10/15/19 | Tue 10/15/19 | 7,8
10 | Present prototype | 0 days | Wed 10/16/19Wed 10/16/19
11 | Setup database | 9 days | Thu 10/17/19Tue 10/29/1910
12 | Connect app to database | 5 days | Wed 10/30/19 | Tue 11/5/19 | 11
13 | Database communications complete | 0 days | Wed 11/6/19 | Wed 11/6/19 | 12
14 | Extra features and quality assurance
14 days | Thu 11/7/19 | Tue
| | | 11/26/19 | 13
15 | Partner meeting | 0 days | Wed 11/27/19Wed 11/27/1914
16 | Write final report | 4 days | Thu 11/28/19Tue 12/3/19 | 14,15

9/19

T | W | T | F | S | S | M | T | W | T | F | S | S
Sep 8, '19 | Sep 15, '19 | Sep 22, '19

Task

Split

Milestone

Summary

Project Summary

Inactive Task

Inactive Milestone

Inactive Summary

Manual Task

Duration-only

Manual Summary Rollup

Manual Summary

Start-only

Finish-only

External Tasks

External Milestone

Deadline

Progress

Manual Progress

### Project: Ceng319 Project Sched Date: Wed 9/25/19

ID | Task
Mode
Task Name | Duration | Start | Finish | Predecessors
17 | Final report and

## presentation

## 0 days Wed

12/4/19

## Wed

12/4/19

16

T | W | T | F | S | S | M | T | W | T | F | S | S
Sep 8, '19 | Sep 15, '19 | Sep 22, '19

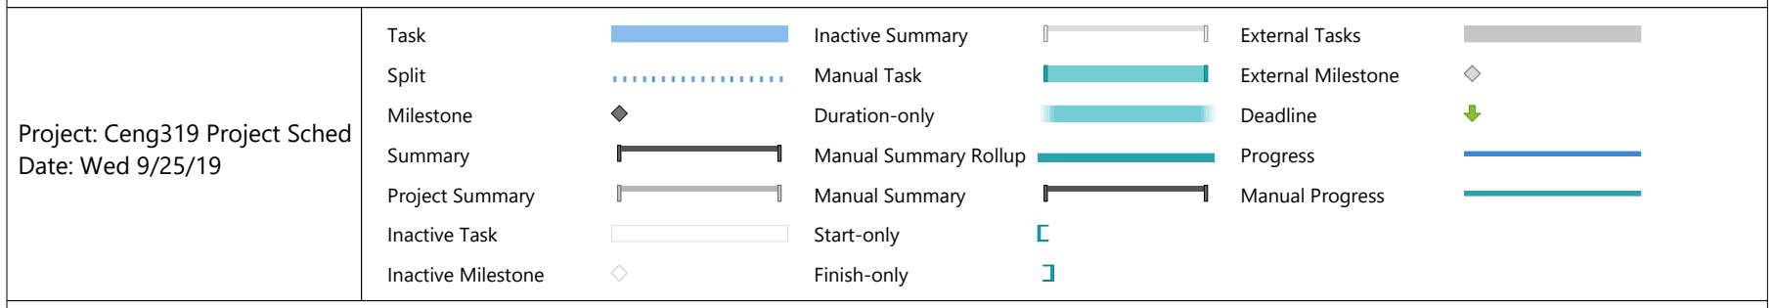
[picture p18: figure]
Task; Split; Milestone; Summary; Project Summary; Inactive Task; Inactive Milestone; Inactive Summary; Manual Task; Duration-only; Manual Summary Rollup; Manual Summary; Start-only; Finish-only; External Tasks; External Milestone; Deadline; Progress; Manual Progress; Project: Ceng319 Project Sched Date: Wed 9/25/19
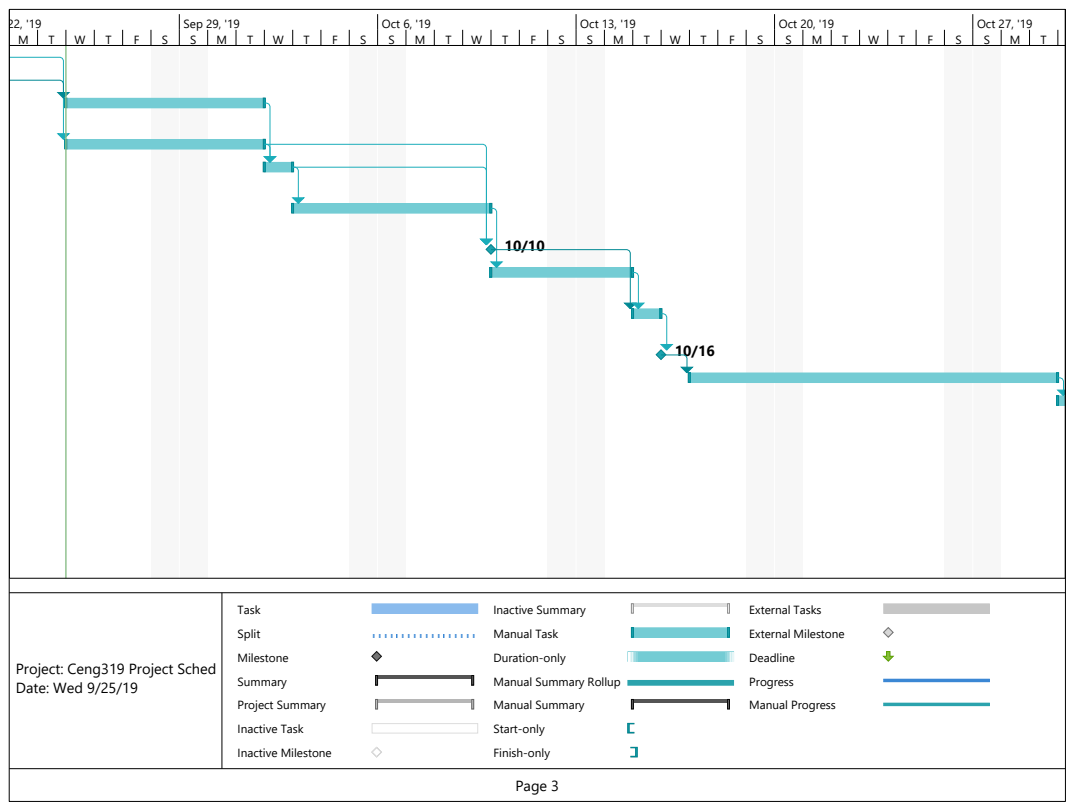
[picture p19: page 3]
Sep 22, '19; Sep 29, '19; Oct 6, '19; Oct 13, '19; Oct 20, '19; Oct 27, '19; Task; Split; Milestone; Summary; Project Summary; Inactive Task; Inactive Milestone; Inactive Summary; Manual Task; Duration-only; Manual Summary; Start-only; Finish-only; External Tasks; External Milestone; Deadline; Progress; Manual Progress

Project: Ceng319 Project Sched
Date: Wed 9/25/19

Manual Summary Rollup

M | T | W | T | F | S | S | M | T | W | T | F | S | S | M | T | W | T | F | S | S | M | T | W | T | F | S | S | M | T | W | T | F | S | S | M | T
Sep 22, '19 | Sep 29, '19 | Oct 6, '19 | Oct 13, '19 | Oct 20, '19 | Oct 27, '19

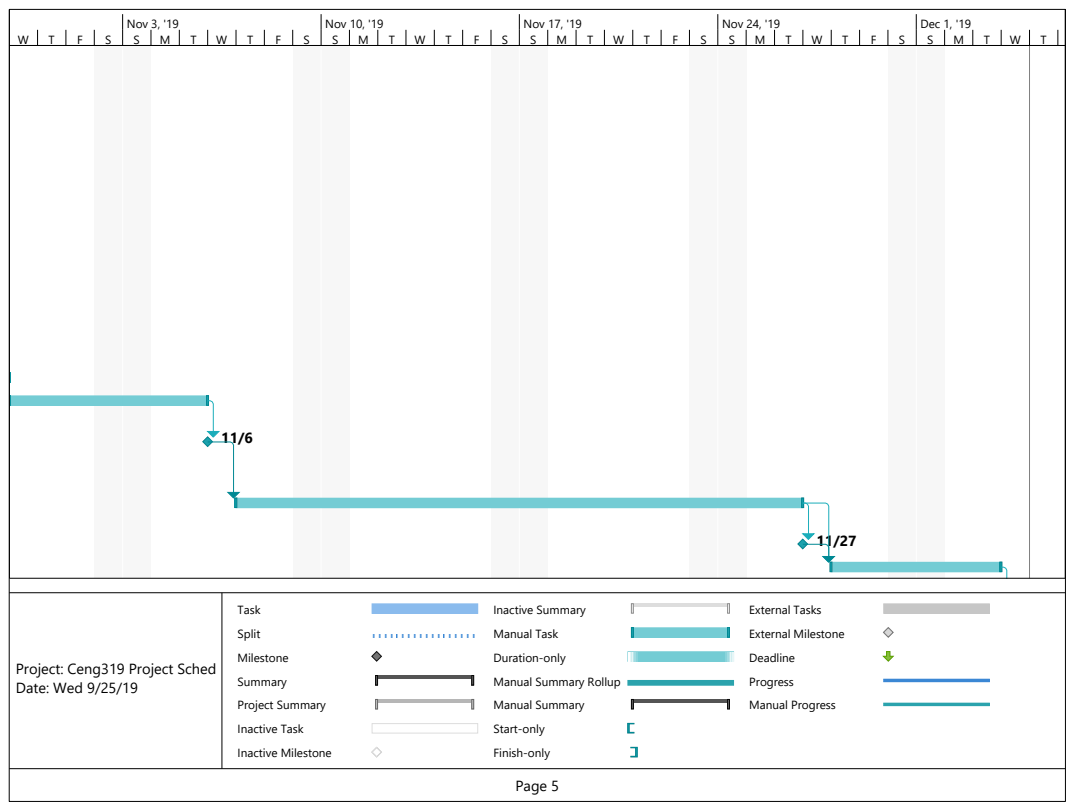
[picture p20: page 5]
Nov 3, '19; Nov 10, '19; Nov 17, '19; Nov 24, '19; Dec 1, '19; Task; Split; Milestone; Summary; Project Summary; Inactive Task; Inactive Milestone; Inactive Summary; Manual Task; Duration-only; Manual Summary; Start-only; Finish-only; External Tasks; External Milestone; Deadline; Progress; Manual Progress

Project: Ceng319 Project Sched
Date: Wed 9/25/19

Manual Summary Rollup

12/4

W | T | F | S | S | M | T | W | T | F | S | S | M | T | W | T | F | S | S | M | T | W | T | F | S | S | M | T | W | T | F | S | S | M | T | W | T
Nov 3, '19 | Nov 10, '19 | Nov 17, '19 | Nov 24, '19 | Dec 1, '19

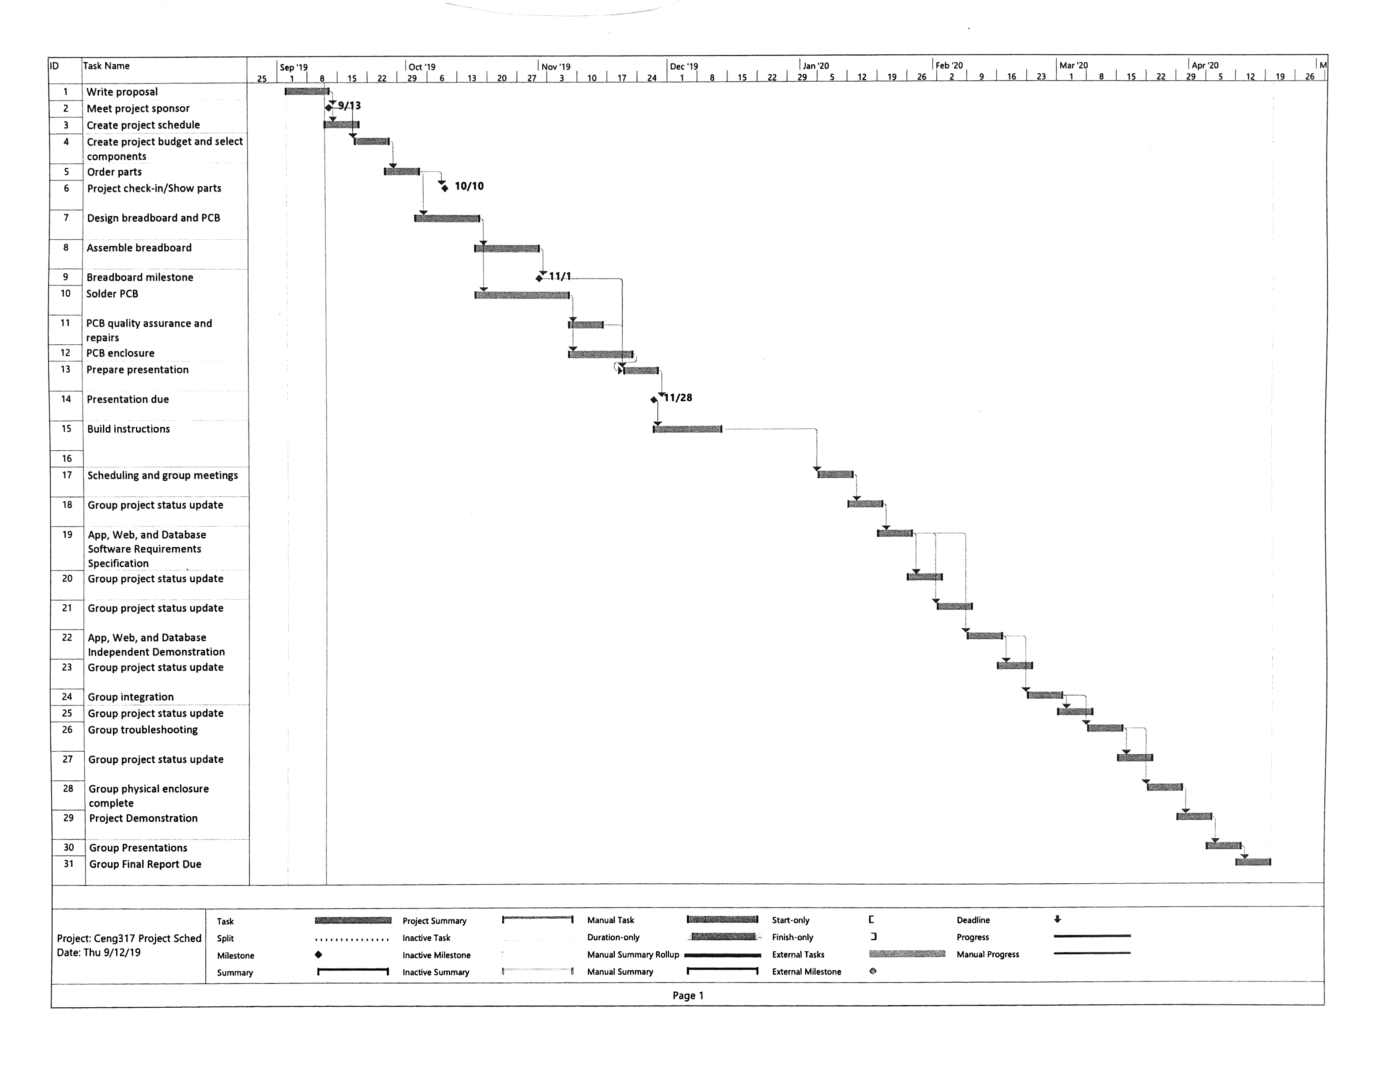
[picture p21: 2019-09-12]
documentation/Hardware (Ceng 317)/Ceng317 Project Schedule BWoo.png

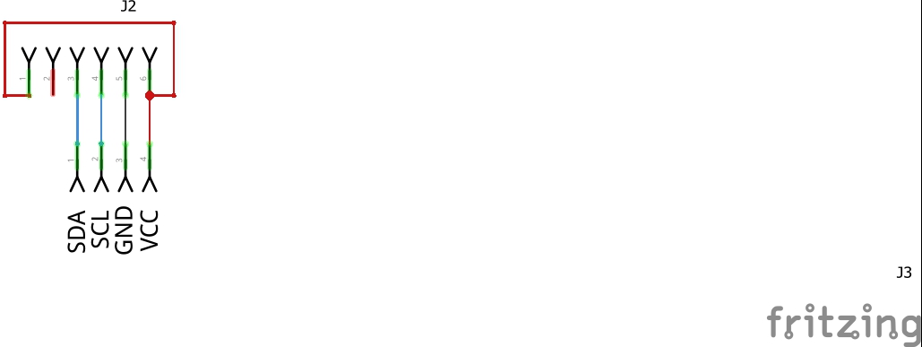
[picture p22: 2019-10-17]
electronics/TOFsensorDesign_schem.jpg

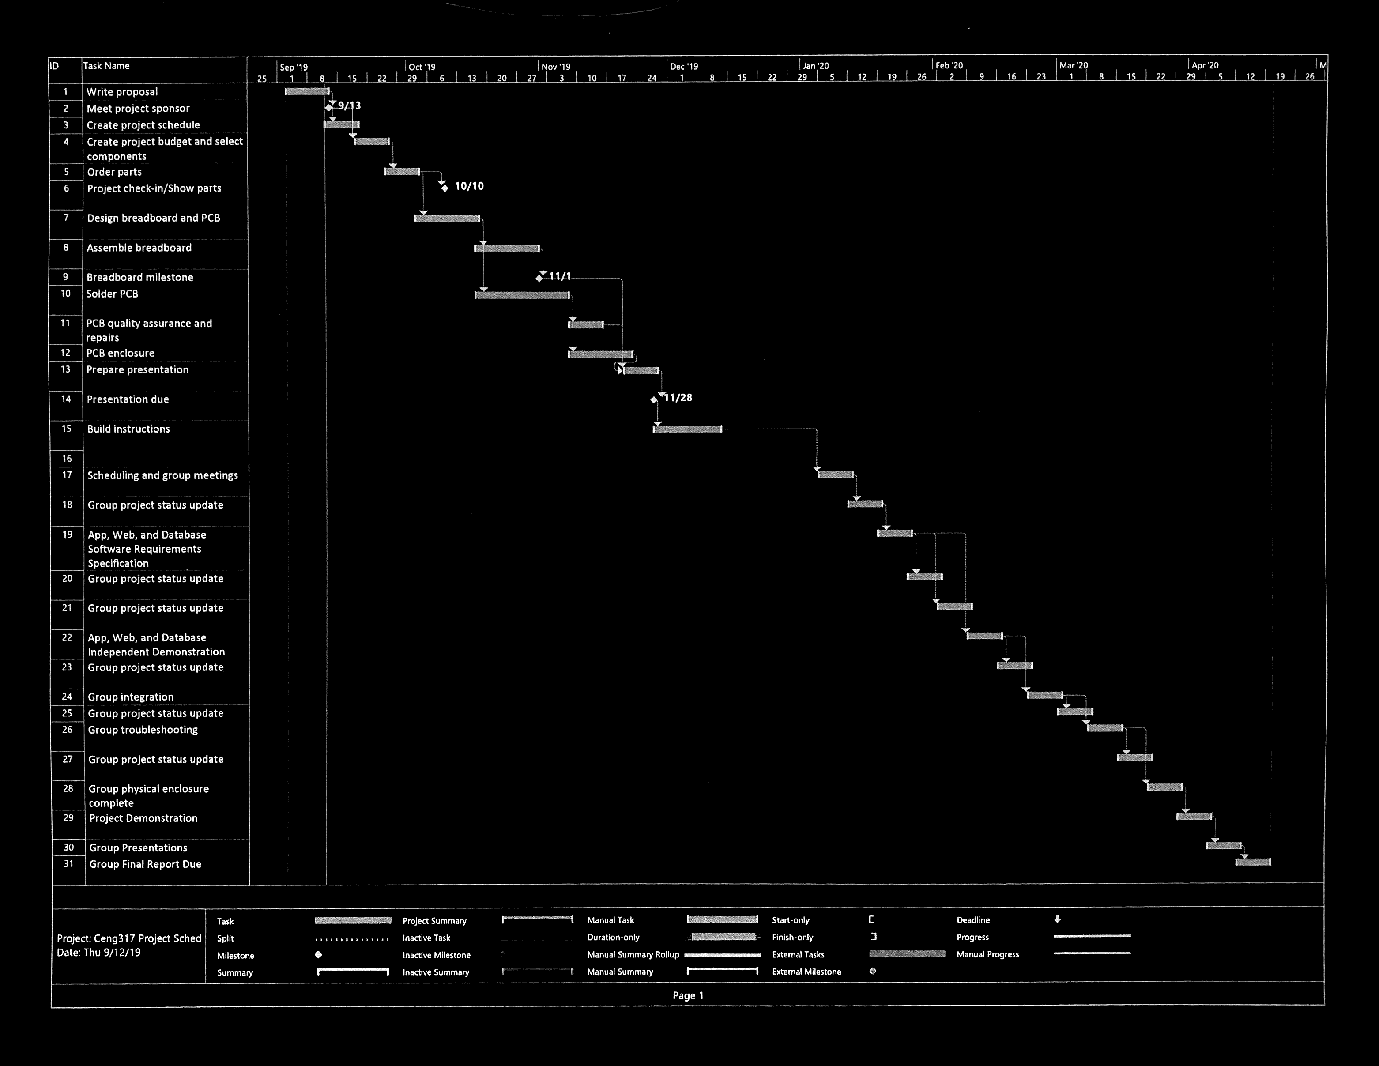
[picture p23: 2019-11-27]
documentation/Hardware (Ceng 317)/Ceng317 Project Schedule BWoo black.png

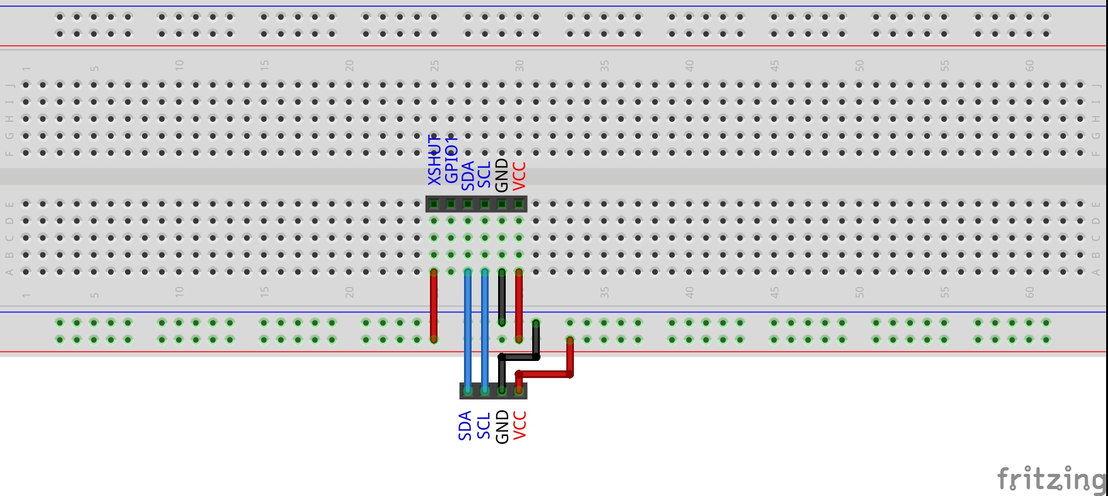
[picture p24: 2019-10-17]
electronics/TOFsensorDesign_bb.jpg

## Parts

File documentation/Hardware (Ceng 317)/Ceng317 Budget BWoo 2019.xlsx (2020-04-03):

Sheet: Budget
Component | Number | Cost | Source | Link
3mm cast acrylic sheet | 1 | $14.95 | Amazon | https://amzn.to/2Ry0JLj
m2.5 screws | 4 | $0.60 | Digikey | https://bit.ly/2t4eDuB
m2.5 nuts | 4 | $0.92 | Digikey | http://bit.ly/35lUwpC
m2 screws | 2 | $0.42 | Digikey | http://bit.ly/2PvBeYw
m2 nuts | 2 | $0.34 | Digikey | http://bit.ly/355GWqq
4 pin header and 6 pin header | 1 | $19.98 | Amazon | https://amzn.to/2PyRhVc
VL53L0X sensor | 1 | $14.95 | Adafruit | https://www.adafruit.com/product/3317
4 F-F wire connectors | 1 | $6.99 | Amazon | https://amzn.to/2RHou3L
Raspberry Pi kit | 1 | $85.37 | Canakit | https://amzn.to/2RHTccP
Total: |  | $144.52

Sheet: My expected budget
TOF sensor for Resistor Value Recognizer
Purchase | Cost | Number | Total cost | Notes | Status | Source
Ultimate Starter Kit for Arduino | $60.59 | 1 | $60.59 | Includes resistors, wires, LED | Already purchased | https://www.amazon.ca/Smraza-Ultimate-Tutorial-Components-Compatible/dp/B073WRCDWM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
VL53L0X TOF sensor | $14.95 | 1 | $14.95 |  |  | https://www.adafruit.com/product/3317
23x11 3mm transparent cast acrylic | $11.30 | 1 | $11.30 | For case | Already purchased | Plasticworld
11x11 3mm black cast acrylic | $5.65 | 1 | $5.65 | For case | Already purchased | Plasticworld
Standoffs M-M (x4) | $2.50 | 1 | $2.50 | For case |  | A1 parts
Standoffs M-F (x2) | $1.50 | 2 | $3.00 | For case |  | A1 parts
Screws | $1.50 | 1 | $1.50 | For case |  | A1 parts
Wires | $0.00 | 0 | $0.00 |  | Already purchased
Raspberry Pi kit | $85.37 | 1 | $85.37 | Current price is lower | Already purchased | https://www.amazon.com/CanaKit-Raspberry-Complete-Starter-Kit/dp/B01C6Q2GSY
Total | $184.86

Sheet: My final Budget
TOF sensor for Resistor Value Recognizer
Purchase | Cost | Number | Total cost | Notes | Status | Source
VL53L0X TOF sensor | $14.95 | 1 | $14.95 |  | Previously purchased | https://www.adafruit.com/product/3317
23x11 3mm transparent cast acrylic | $11.30 | 1 | $11.30 | For case | No cost | Supplied by prototype lab
Screws | $1.50 | 1 | $1.50 | For case | No cost | Supplied by prototype lab
Wires | $0.00 | 0 | $0.00 |  | Previously purchased
Header pin and connectors | $5.57 | 1 | $5.57 |  |  | Sayal
Raspberry Pi kit | $85.37 | 1 | $85.37 | Current price is lower | Previously purchased | https://www.amazon.com/CanaKit-Raspberry-Complete-Starter-Kit/dp/B01C6Q2GSY
Expected budget | $118.69
Total | $105.89
Total project-specific | $5.57

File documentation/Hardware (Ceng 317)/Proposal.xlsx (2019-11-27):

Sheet: DataEntry
Submission Date | 2019-09-12
Project Name | Resistor value recognizer
Student Names | Brendan Woo, Husnal Kaur
Project repository | https://github.com/BW25/Resistor-value-recognizer
SensorsEffectors choices | Time of Flight sensor , luminosity sensor, camera
The database will store | User account information, History of recognized resistors, Resistor color code lookup table
The mobile device functionality will include | Viewing value of resistor, Viewing history, Color code table with values
I will be collaborating with the following company/department | Humber parts crib
My group in the winter semester will include | Brendan Woo, Husnal Kaur
50 word problem statement | Due to the large volume of students that use the parts crib, large amounts of unsorted components often accumulate. High traffic makes it difficult to sort these components, and it is often time consuming to figure out each and every value of the resistors. Also, it can be hard to identify resistor values correctly in a fast paced environment.
100 words of background | When a component is inserted into a processing area, image processing and machine learning will be used to recognize resistor values through object and colour recognition. Once the resistor's value has been found, this can be logged in a database to track usage. This information can be accessed by an Android app so the user’s ID can be used to look up their history. A TOF sensor will be used to detect when an object is inserted. As image processing techniques are dependent on lighting, a luminosity sensor will be used to trigger a lighting system to ensure ideal lighting conditions are always present. The TOF sensor will then trigger both the camera and the lighting system for greater energy efficiency.
Current product APA citation | Amazon. (2019, September 05). Amazon Go. Retrieved from Amazon.com: https://www.amazon.com/b?node=16008589011
Existing research IEEE paper APA citation | Cruz, J., Dimaala, M., Francisco, L., Franco, E., & Bandala, A. (2013). Object recognition and detection by shape and color pattern recognition utilizing Artificial Neural Networks. 2013 International Conference of Information and Communication Technology (ICoICT).
Brief description of planned purchases | cast acrylic for component casings, TOF sensor, luminosity sensor, Raspberry Pi camera module, assorted screws, standoffs, and bolts
Solution description | This system will make it easier for both students and professionals to recognize resistor values in a fast and efficient manner.

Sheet: DataBase
Submission Date | Project Name | Student Names | Project repository | SensorsEffectors choices | The database will store | The mobile device functionality will include | I will be collaborating with the following company/department | My group in the winter semester will include | 50 word problem statement | 100 words of background | Current product APA citation | Existing research IEEE paper APA citation | Brief description of planned purchases | Solution description
43720 | Resistor value recognizer | Brendan Woo, Husnal Kaur | https://github.com/BW25/Resistor-value-recognizer | Time of Flight sensor , luminosity sensor, camera | User account information, History of recognized resistors, Resistor color code lookup table | Viewing value of resistor, Viewing history, Color code table with values | Humber parts crib | Brendan Woo, Husnal Kaur | Due to the large volume of students that use the parts crib, large amounts of unsorted components often accumulate. High traffic makes it difficult to sort these components, and it is often time consuming to figure out each and every value of the resistors. Also, it can be hard to identify resistor values correctly in a fast paced environment. | When a component is inserted into a processing area, image processing and machine learning will be used to recognize resistor values through object and colour recognition. Once the resistor's value has been found, this can be logged in a database to track usage. This information can be accessed by an Android app so the user’s ID can be used to look up their history. A TOF sensor will be used to detect when an object is inserted. As image processing techniques are dependent on lighting, a luminosity sensor will be used to trigger a lighting system to ensure ideal lighting conditions are always present. The TOF sensor will then trigger both the camera and the lighting system for greater energy efficiency. | Amazon. (2019, September 05). Amazon Go. Retrieved from Amazon.com: https://www.amazon.com/b?node=16008589011 | Cruz, J., Dimaala, M., Francisco, L., Franco, E., & Bandala, A. (2013). Object recognition and detection by shape and color pattern recognition utilizing Artificial Neural Networks. 2013 International Conference of Information and Communication Technology (ICoICT). | cast acrylic for component casings, TOF sensor, luminosity sensor, Raspberry Pi camera module, assorted screws, standoffs, and bolts | This system will make it easier for both students and professionals to recognize resistor values in a fast and efficient manner.

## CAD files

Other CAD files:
mechanical/hardwareEnclosure.dwg

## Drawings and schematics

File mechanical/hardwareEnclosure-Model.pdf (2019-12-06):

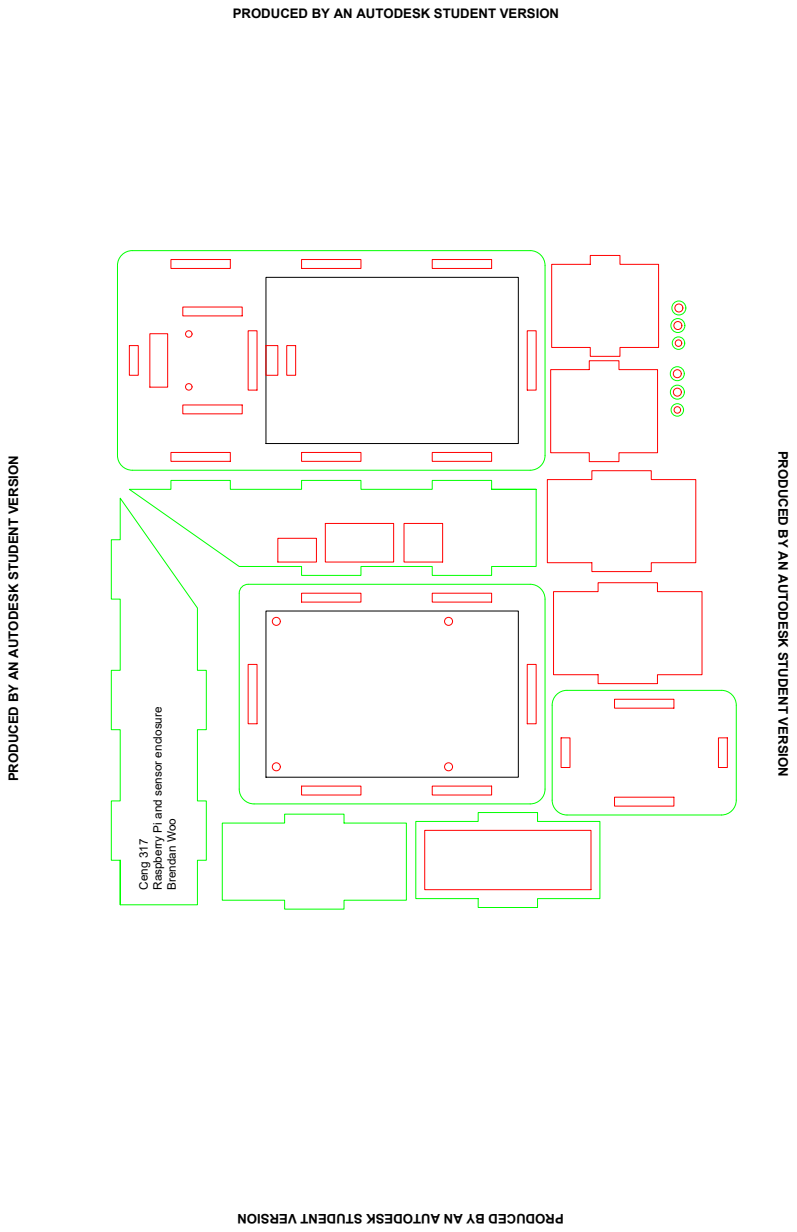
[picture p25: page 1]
Ceng 317; Brendan Woo

PRODUCED BY AN AUTODESK STUDENT VERSION

Raspberry Pi and sensor enclosure

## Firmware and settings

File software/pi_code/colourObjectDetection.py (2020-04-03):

# -*- coding: utf-8 -*-
"""
Created on Fri Sep  6 18:03:13 2019

@author: bdwoo
"""
import cv2
import numpy as np
import sys

#TODO: 
#   Order resistor colour codes
#   Calc average V and use to adjust V for lighting intensity
#   Locate resistor based on contour or tan/blue colour

#Resources
"""
https://sites.google.com/site/ohmcalcucsb/
https://github.com/windmill-cloud/AndroidEmb/blob/master/OhmCalcBase/app/src/main/java/edu/ucsb/ece/ece150/ohmcalcbase/OhmCalcImageProcessor.java

https://hackaday.com/2015/05/14/reading-resistors-with-opencv/
https://github.com/thegouger/ResistorScanner
"""

"""
class ColourCode:
    def __init__(self, rVal):
        self.name = rVal
        self.prev = None
        self.prevVal = None
        self.next = None
        self.nextVal = None
        
    def __str__(self):
        return self.name
    
    def getName(self):
        return self.name
    def getPrev(self):
        return self.prev
    def getNext(self):
        return self.next
    
    def setName(self, name):
        self.name = str(name)
    def setPrev(self, prev):
        self.prev = prev
    def setNext(self, next):
        self.next = next
        
class ColourCodeSort:
    def __init__(self, rValList):
        self.rValList = rValList
        self.distances = []
        self.rValCodes = []
        
        
    def __str__(self):
        return rValList
    

    #Get the two closest contours and their distances with Pythagorean
    def calcClosestDistances(self):

        if len(self.rValList) > 1:
            self.distances = []
        
            #Loop through the rValList
            for i in range(len(self.rValList)):
                min1 = sys.maxsize
                min2 = sys.maxsize
                closest1 = None
                closest2 = None
                x = self.rValList[i][1]
                y = self.rValList[i][2]
                self.distances.append(1)
                
                #For each value, look through the list and find the two closest
                for j in range(len(self.rValList)):
                    #Don't check a value against itself
                    if i != j:
                        distance = np.sqrt(np.square(x-self.rValList[j][1]) + np.square(y-self.rValList[j][2]))
                        if distance < min1:
                            #Ensure a new smaller value does not overwrite the old one, but stores as second smallest
                            if min1 != sys.maxsize:
                                min2 = min1
                                closest2 = closest1
                            min1 = distance
                            closest1 = j
                        elif distance < min2:
                            min2 = distance
                            closest2 = j
                #Store the closest distances for each
                val1 = None if closest1 == None else self.rValList[closest1][0]
                val2 = None if closest2 == None else self.rValList[closest2][0]
                
                #Store indexes of 2 closest contours
                self.distances.append((closest1, closest2, min1, min2))
                
        def calcColourCode(self):
            if len(self.distances) > 1:
                #Find one end of the resistor: look for gold
                
def calcColourCodeV2():
    global rValList
        
    sort = ColourCodeSort(rValList)
    sort.calcClosestDistances()
    
    #Find smallest Pythagorean distance between resistor codes
    #Use to sort list based on their relationship to each other
    #Obtain ordered list of colour codes in order
    
    #For Husnal:
    #Check first value. If it is a tolerance, go backwards, otherwise, go forwards
"""

#Make thesh global so it can be accessed by trackbar callbacks
thresh = []

#Update global threshold values on trackbar callback
#Safety to ensure min is always smaller than max
def updateHmin1(val):
    global thresh
    thresh['hMin'] = min(thresh['hMax']-1, val)
    cv2.setTrackbarPos('H1 min', 'Threshold', thresh['hMin'])
def updateHmax1(val):
    global thresh
    thresh['hMax'] = max(thresh['hMin']+1, val)
    cv2.setTrackbarPos('H1 max', 'Threshold', thresh['hMax'])
def updateSmin1(val):
    global thresh
    thresh['sMin'] = min(thresh['sMax']-1, val)
    cv2.setTrackbarPos('S1 min', 'Threshold', thresh['sMin'])
def updateSmax1(val):
    global thresh
    thresh['sMax'] = max(thresh['sMin']+1, val)
    cv2.setTrackbarPos('S1 max', 'Threshold', thresh['sMax'])
def updateVmin1(val):
    global thresh
    thresh['vMin'] = min(thresh['vMax']-1, val)
    cv2.setTrackbarPos('V1 min', 'Threshold', thresh['vMin'])
def updateVmax1(val):
    global thresh
    thresh['vMax'] = max(thresh['vMin']+1, val)
    cv2.setTrackbarPos('V1 max', 'Threshold', thresh['vMax'])
    
#Select a subregion of the image where the resistor is
def getResistorLoc(frame, threshList, kernel):
    #Convert to HSV colourspace, which is better for colour detection
    hsvFrame = cv2.cvtColor(frame, cv2.COLOR_BGR2HSV)
    
    height, width, _ = hsvFrame.shape
    mask = np.zeros((height, width), np.uint8)
    for thresh in threshList:
        mask = cv2.bitwise_or(mask, cv2.inRange(hsvFrame, (thresh['hMin'], thresh['sMin'], thresh['vMin']), (thresh['hMax'], thresh['sMax'], thresh['vMax'])))
    
    #Opening consists of eroding, then dilating
    #erode to remove false positive noise
    mask = cv2.erode(mask, kernel, iterations=1)
    #dilate to undo the effect of erode on our object, and remove false negative noise
    mask = cv2.dilate(mask, kernel, iterations=2)
    
    contours, hierarchy = cv2.findContours(mask, cv2.RETR_EXTERNAL, cv2.CHAIN_APPROX_NONE)
   
    height, width, _ = hsvFrame.shape
    minX = width
    minY = height
    maxX = 0
    maxY = 0
    
    for c in contours:
        moment = cv2.moments(c)
        area = moment['m00']
        
        if area > 250:
            #Find the bounds for the ROI rectangle
            (cX,cY,w,h) = cv2.boundingRect(c)
            minX, maxX = min(cX, minX), max(cX+w, maxX)
            minY, maxY = min(cY, minY), max(cY+h, maxY)
            
            x = int(moment['m10']/area)
            y = int(moment['m01']/area)
                        

    #print('minX:' + str(minX) + ' maxX' + str(maxX) + '  minY:' + str(minY) + ' maxY' + str(maxY))
    cv2.rectangle(hsvFrame, (minX,minY), (maxX,maxY), (0,0,255), 2)
    
    return frame[minY:maxY, minX:maxX], hsvFrame[minY:maxY, minX:maxX]


def getColourContours(roi, roihsv, thresh, text, kernel, rValList):
    #filter out colours in range using the values from the trackbars
    mask = cv2.inRange(roihsv, (thresh['hMin'], thresh['sMin'], thresh['vMin']), (thresh['hMax'], thresh['sMax'], thresh['vMax']))
    
    #Opening consists of eroding, then dilating
    #erode to remove false positive noise
    mask = cv2.erode(mask, kernel, iterations=1)
    #dilate to undo the effect of erode on our object, and remove false negative noise
    mask = cv2.dilate(mask, kernel, iterations=2)
    
        #hierarchy describes how contours are nested.
    #RETR_EXTERNAL says we only take the outermost contour, so there is no hierarchy
    #Stores the points representing the boundary of the contours
    #APPROX_SIMPLE approximmates the object to minimize the number of points to save memory
    #APPROX_NONE makes no approximations, and stores more points
    contours, hierarchy = cv2.findContours(mask, cv2.RETR_EXTERNAL, cv2.CHAIN_APPROX_NONE)
   
        #Hierarchy at [i][0] is the index of the next contour at the same level. When it is negative, there are no more contours
    for c in contours:
        moment = cv2.moments(c)
        area = moment['m00']
        
        if area > 250:
            x = int(moment['m10']/area)
            y = int(moment['m01']/area)
            
            #cv2.circle(roi, (x,y), 3, (255,0,0), 2)
            write(roi, text, x, y)
            
            #Add the locations to the rValList, which tracks the locations and values of resistor colour codes
            rValList.append((text, x, y))
            
            #input image, contours array, contours to draw, colour to draw with, line width (if -ve, interiour of contour filled)
            cv2.drawContours(roi, c, -1, (0, 255, 0), 2)
    
    return mask


def write(frame, text, x, y):
    cv2.putText(
     frame, #numpy array on which text is written
     text, #text
     (int(x), int(y)), #position at which writing has to start
     cv2.FONT_HERSHEY_SIMPLEX, #font family
     1, #font size
     (255, 0, 0)) #font color
    
#Blindly get colours from left to right
def calcColourCodeV1(rValList):
    #Make a new list of rVals from left to right
    lToR = []
    
    #Go until entire list is empty
    for i in range(len(rValList)):
        
        minX = rValList[0]
        #Find smallest x value (leftmost) and store in list
        for val in rValList[1:]:
            if val[1] < minX[1]:
                minX = val
                
        #Add the smallest item to the sorted list and get rid of the old value
        lToR.append(minX[0])
        rValList.remove(minX)
        
    return lToR

#Lookup for colour codes
def color_string(n):
    switcher={
            0:'black',
            1:'brown',
            2:'red',
            3:'orange',
            4:'yellow',
            5:'green',
            6:'blue',
            7:'violet',            
            8:'grey',
            9:'white',
            10:'gold'
            }
    return switcher.get(n, 'invalid')


def readColourCodes(debug=False):
    global thresh
    
    #Create the kernel to be used for eroding. Be sure to use numpy, or it will be slow
    kernel = np.ones((5, 5), np.uint8)

    #Test values for markers
    """
    orangeThresh = {'hMin' : 0, 'hMax' : 10, 'sMin' : 178, 'sMax' : 255, 'vMin' : 220, 'vMax' : 255}
    yellowThresh = {'hMin' : 21, 'hMax' : 38, 'sMin' : 78, 'sMax' : 255, 'vMin' : 129, 'vMax' : 232}

    orangeThreshLowLight = {'hMin' : 0, 'hMax' : 10, 'sMin' : 140, 'sMax' : 255, 'vMin' : 72, 'vMax' : 174}
    yellowThreshLowLight = {'hMin' : 21, 'hMax' : 38, 'sMin' : 133, 'sMax' : 255, 'vMin' : 29, 'vMax' : 133}
    """

    rBackingColour = []
    rBackingColour.append({'hMin' : 0, 'hMax' : 20, 'sMin' : 45, 'sMax' : 144, 'vMin' : 53, 'vMax' : 181}) #tan
    rBackingColour.append({'hMin' : 81, 'hMax' : 194, 'sMin' : 82, 'sMax' : 191, 'vMin' : 12, 'vMax' : 166}) #blue
    rBackingColour.append({'hMin' : 0, 'hMax' : 190, 'sMin' : 70, 'sMax' : 144, 'vMin' : 53, 'vMax' : 181}) #burnt umber (same as tan, but hMax is 190


    #Create list of thresholds for each colour code
    codeThresh = []
    
    codeThresh.append({'hMin' : 0, 'hMax' : 165, 'sMin' : 0, 'sMax' : 250, 'vMin' : 0, 'vMax' : 65})    #Black
    codeThresh.append({'hMin' : 114, 'hMax' : 205, 'sMin' : 70, 'sMax' : 125, 'vMin' : 44, 'vMax' : 148})    #Brown
    codeThresh.append({'hMin' : 148, 'hMax' : 185, 'sMin' : 105, 'sMax' : 172, 'vMin' : 59, 'vMax' : 200})    #Red
    codeThresh.append({'hMin' : 0, 'hMax' : 12, 'sMin' : 100, 'sMax' : 137, 'vMin' : 20, 'vMax' : 243})    #Orange
    codeThresh.append({'hMin' : 11, 'hMax' : 27, 'sMin' : 30, 'sMax' : 119, 'vMin' : 70, 'vMax' : 255})    #Yellow
    codeThresh.append({'hMin' : 56, 'hMax' : 117, 'sMin' : 0, 'sMax' : 130, 'vMin' : 0, 'vMax' : 180})    #Green
    codeThresh.append({'hMin' : 105, 'hMax' : 117, 'sMin' : 132, 'sMax' : 177, 'vMin' : 33, 'vMax' : 255})    #Blue
    codeThresh.append({'hMin' : 118, 'hMax' : 152, 'sMin' : 67, 'sMax' : 134, 'vMin' : 45, 'vMax' : 185})    #Violet
    codeThresh.append({'hMin' : 113, 'hMax' : 140, 'sMin' : 18, 'sMax' : 58, 'vMin' : 00, 'vMax' : 185})    #Grey proto
    codeThresh.append({'hMin' : 117, 'hMax' : 160, 'sMin' : 16, 'sMax' : 34, 'vMin' : 151, 'vMax' : 255})    #White proto

    #codeThresh.append({'hMin' : 0, 'hMax' : 15, 'sMin' : 40, 'sMax' : 86, 'vMin' : 83, 'vMax' : 255})    #Gold proto

    #Set up trackbars to adjust a specific threshold if debug mode
    if (debug):
        thresh = codeThresh[1]
        cv2.namedWindow('Threshold')
        cv2.createTrackbar('H1 min', 'Threshold', thresh['hMin'], 255, updateHmin1)
        cv2.createTrackbar('H1 max', 'Threshold', thresh['hMax'], 255, updateHmax1)
        cv2.createTrackbar('S1 min', 'Threshold', thresh['sMin'], 255, updateSmin1)
        cv2.createTrackbar('S1 max', 'Threshold', thresh['sMax'], 255, updateSmax1)
        cv2.createTrackbar('V1 min', 'Threshold', thresh['vMin'], 255, updateVmin1)
        cv2.createTrackbar('V1 max', 'Threshold', thresh['vMax'], 255, updateVmax1)


    video = cv2.VideoCapture(0)
    ret, frame = video.read()
    width, height = frame.shape[:2]


    while True:
        ret, frame = video.read()
        
        #Create the list to store the values and locations of resistor colour codes
        rValList = []
        
        
        #Flip the frame so it isn't backwards
        frame = cv2.flip(frame, 1)

        

        """
        orangeMask = getColourContours(hsv, orangeThresh, "Orange")
        yellowMask = getColourContours(hsv, yellowThresh, "Yellow")
        
        finalMask = cv2.bitwise_or(orangeMask, yellowMask)
        """
        
        #TODO (optional): locate resistor location by base colour using boundingRect around contours
        #Search each submat at this location individually for resistor colour codes to scan multiple resistors
        #Potential problem: colour will be split into several contours due to colour codes
        roi, roihsv = getResistorLoc(frame, rBackingColour, kernel)
        
        height, width, _ = roi.shape
        if height > 0 and width > 0: 
            #Acquire all masks for all colour codes
            maskList = []
            for i in range(len(codeThresh)):
                maskList.append(getColourContours(roi, roihsv, codeThresh[i], color_string(i), kernel, rValList))
            
            finalMask = maskList[0]
            for i in range(1, len(maskList)):
                finalMask = cv2.bitwise_or(finalMask, maskList[i])
                
            #TODO: Alter rValList to contain the size of the contours
            #If we expect 4 bands, only keep the four largest contours to remove contours split in half
                
            
            print('Values')
            print(rValList)
            
            codes = calcColourCodeV1(rValList)
            #calcColourCodeV2()
            
            cv2.imshow("Filter", finalMask)
            cv2.imshow("Contours", roi)
            
            #Only loop continously in debug mode. Otherwise, just take a single picture
            if not debug:
                break

            if cv2.waitKey(200) & 0xFF == ord('q'):
                break

    video.release()
    cv2.destroyAllWindows()
    return codes



if __name__ == '__main__':
    print(readColourCodes(debug=True))

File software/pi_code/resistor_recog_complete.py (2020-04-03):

import random
import pyrebase  # You can use the pyrebase library to work on the firebase connection from Raspberry Pi
import time
import math

import colourObjectDetection
import Color_recog

from VL53L0X_rasp_python_master.python import VL53L0X
import RPi.GPIO as GPIO


ledPin = 18


def databaseinit():
  global db
  global dev_id
  
  authFile = open('authFile','r')
  if authFile.mode == 'r':
      authList = authFile.read().split(':')
      apiKey = authList[0]
      dev_id = authList[1]
      
  
      config = {
            "apiKey": apiKey,
            "authDomain": "rvr-resistor-value-recognizer.firebaseapp.com",
            "databaseURL": "https://rvr-resistor-value-recognizer.firebaseio.com",
            "storageBucket": "rvr-resistor-value-recognizer.appspot.com"
          }
      firebase = pyrebase.initialize_app(config)
      db = firebase.database()
  authFile.close()
  
def tofInit():
    # Create a VL53L0X object
    tof = VL53L0X.VL53L0X(address=0x2B)

    # Start ranging
    tof.start_ranging(VL53L0X.VL53L0X_BETTER_ACCURACY_MODE)
    return tof

def lightTofCtrl(ledPwm):
    ledPwm.ChangeDutyCycle(0)
    
    distance = tof.get_distance()
    if (distance < 100):
        ledPwm.ChangeDutyCycle(100)
        
    
def ledInit():
    GPIO.setmode(GPIO.BCM)
    GPIO.setup(ledPin, GPIO.OUT)

    pwm = GPIO.PWM(ledPin, 100) #100 Hz
    pwm.start(0)
    return pwm



if __name__ == '__main__':
  databaseinit()
  
  if (dev_id != None):
      tof = tofInit()
      ledPwm = ledInit()
      
      
      while (True):
          try:
              lightTofCtrl(ledPwm)
              
              
              
              #Get the requestcode for this device
              request = db.child('devices').child(dev_id).child('request').get()
              print('Requestcode: ' + str(request.val()))
              
              #If the requestcode is not 0, take a scan and update the database
              if (request.val() != 0):
                  
                  code = colourObjectDetection.readColourCodes(debug=True)
                  codeStr = Color_recog.code2str(code)
                  
                  #Create the data
                  data = {'device':dev_id, 'timestamp':time.ctime(time.time()), 'type':None, 'value':codeStr}
                  
                  try:
                      #Push the data into the historydata of the user ID given in the requestcode
                      db.child('historydata').child(request.val()).push(data)
                      
                      db.child('devices').child(dev_id).child('request').set(0)
                      print('scan uploaded')
                      print(data)
                  except Exception as e:
                     print ("Database cannot be written, check the permission on database or the requestcode")
                     print(str(e))
                     
              #Check for a request every 2 seconds. Also controls how long lights stay on  
              time.sleep(2)
              
              
                  
          except KeyboardInterrupt:
              break
            
      tof.stop_ranging()
      pwm.stop()
      GPIO.cleanup()
      
  else:
      print('No device id found')

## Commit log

2019-09-12 Adding additional proposal files to documentation
    [Proposal.xlsx]
2019-09-26 Create Ceng317 Budget BWoo 2019.xlsx
    Adding project budget to documentation
    [Ceng317 Budget BWoo 2019.xlsx]
2019-09-26 Reorganizing software folder and adding image
    [Ceng317 Budget BWoo 2019.xlsx, Proposal.xlsx]
2019-09-30 Updating documentation to use TOF sensor
    [Ceng317 Budget BWoo 2019.xlsx]
2019-09-30 Updating documentation for TOF sensor
    [Proposal.xlsx]
2019-10-10 Updating Activity template and AddDevice activity
    [TOFsensorDesign.fzz]
2019-10-11 Moving app to separate repository
    [TOFsensorDesign.fzz]
2019-10-17 Uodating breadboard and pcb
    [TOFsensorDesign.fzz, TOFsensorDesignWPi.fzz]
2019-10-17 Updating Fritzing files
    [TOFsensorDesign.fzz, TOFsensorDesignWPi.fzz]
2019-10-17 Adding PCB Gerber files
    [TOFsensorDesign.fzz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]
2019-10-31 Adding breadboard demo images
    [TOFsensorDesign.fzz]
2019-11-21 Updating PCB case and images
    [hardwareEnclosure.dwg]
2019-11-27 Updating documentation and adding presentation
    [Ceng317 Budget BWoo 2019.xlsx, Proposal.xlsx]
2019-12-05 Updating hardware enclosure
    [hardwareEnclosure.dwg]
2019-12-05 Adding code
    [Ceng317 Budget BWoo 2019.xlsx]
2019-12-05 Updating budget
    [Ceng317 Budget BWoo 2019.xlsx]
2019-12-05 Updating budget (again)
    [Ceng317 Budget BWoo 2019.xlsx]
2019-12-06 Updating hardware enclosure pdf
2019-12-10 Update Ceng317 Budget BWoo 2019.xlsx
    Updating budget for build instructions
    [Ceng317 Budget BWoo 2019.xlsx]
2020-04-03 Add Pi code
    [Ceng317 Budget BWoo 2019.xlsx]
